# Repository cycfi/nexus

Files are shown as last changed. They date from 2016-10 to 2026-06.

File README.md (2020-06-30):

# Nexus
The Nexus is a small, flexible, and hacker friendly breakout box that connects your multichannel guitar to the outside world using a specialized (LEMO compatible) multi-pin connector for up to 15 channels of audio and 7 channels of analog control voltages for by-wire (remote) control of volume, tone, patch or effects. Audio may come from standard mono-pickups or from the Nu multichannel pickup. Analog control voltages are converted to MIDI control messages.

Refer to this repository to get the Eagle libraries used in our schematic and pcb files: https://github.com/cycfi/eagle_common

Hardware design files licensed under a [Creative Commons Attribution-ShareAlike 4.0 International License](https://creativecommons.org/licenses/by-sa/4.0/).

Software source code distributed under the [MIT License](https://opensource.org/licenses/MIT).

http://www.cycfi.com/

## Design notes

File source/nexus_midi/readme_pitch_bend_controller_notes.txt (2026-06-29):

Pitch Bend Controller
=====================

The pitch bend controller reads the eWhammy pedal's analog sensor and converts
it into 14-bit MIDI pitch bend messages. The whole design exists to solve one
hard problem: keep the output dead-centered at rest (no off-center "latch", no
drift, no crosstalk spikes) WITHOUT flattening real playing -- bends, vibrato,
and slow expressive moves must pass through faithfully.

It is built as a pipeline of small, independently unit-tested processor blocks
(see test/unit_blocks.cpp). The blocks sorted by reusability: the generally
reusable ones (slew_gate, stillness, dc_servo) live in util.hpp; the
pitch-specific ones (inertial_corrector, output_stage, settle_gate,
freeze_watchdog) sit next to this controller in nexus_controls.hpp.

Signal Path (per loop)
----------------------

Each loop the controller runs this chain (pitch_bend_controller::operator()):

  raw_adc            background oversampler -> a 12-bit reading (10-bit ADC
                     + 2 oversampling bits, os_shift = 2; full scale 4095)
    |
  slew_gate          reject faster-than-physical jumps and HOLD the last good
                     reading (not clamp). The arm slews at most ~6 LSB/ms; a
                     programmer-contact glitch shifts the ADC reference ~10x
                     faster, so it is rejected at the source -- the cause of the
                     old off-center latch. Real motion passes untouched.
    |
  dynamic_smoother   adaptive low-pass (re-ported Q / Cytomic). Its cutoff opens
                     with the bandpass energy, so it tracks fast gestures with
                     low lag and smooths hard at rest (G0 = 24, Sense = 128).
                     Replaces the old lp1<8>+lp2<16> cascade (~30 ms release lag).
    |
  settle_gate        STARTUP only: hold the output at center until the input is
                     a genuinely settled rest (in [1600,2560], stable within
                     24 LSB for 300 ms, and at least 5 s past boot). Then seed
                     the C0 servo from it and go live. Suppresses the power-on
                     swing as Vcc ramps; a disconnected pedal stays silently
                     centered and hot-plugs cleanly.
    |
  deflection         (pos - 2048) * 4  ->  a 14-bit signed deflection
    |
  C0 servo (dc_servo)  the live DC center estimate. dev = deflection - C0 is
                     what becomes the output. See "Centering" below.
    |
  inertial_corrector THE sole centering path. Tracks the bend; lands only a
                     HANG (a release that stalls near zero) back to center.
    |
  + center (8192)    offset-binary MIDI form: 8192 = no bend
    |
  out_ma             3-point moving average -- softens a 1-LSB residual toggle
    |
  output_stage       send deadband (+/-16) with a center-snap exception, then
                     the symmetric x1.2 output gain (307/256) applied to ONLY
                     the value handed to MIDI. Emits the 14-bit message.
    |
  freeze_watchdog    last-resort backstop (runs after the send): flush an output
                     that is genuinely stuck off-center back to center.

Centering: the C0 servo + the inertial_corrector
-------------------------------------------------

Centering is split into two decoupled stages so that nothing in the bend path
can feed the center estimate (the old failure mode: a servo that chased the
bend, then stranded the release off-center).

C0 servo (dc_servo<16, 546, 736>) -- the slow baseline. A VERY slow leaky
integrator (tau ~65 s) that tracks ONLY the thermal/mechanical DC drift of the
rest position. It steps toward the raw deflection only when the bar is STILL
(stillness<32,400>: settled within ~2 LSB for 400 ms) AND near neutral
(|dev| <= c0_gate = 546, ~0.8 ST). A real bend (past the gate) FREEZES it, so a
sustained bend is never absorbed as drift. It is hard-clipped to its seed
+/- c0_clip (736, the max physical DC wander), so even a detection slip can
never drag the center onto a real bend.

inertial_corrector -- the return profile. It passes the deflection through
while the bar moves, and lands ONLY a hang: a release that STOPS near zero. The
mechanics:
  * STALL  -- a stop is detected by low-passed SLOPE (slope_k = 3): when the
    smoothed per-loop slope drops below stall_slope = 14, the bar has stopped.
  * ARM    -- landing is armed only after the bar bends past +/-4 ST (bend_th =
    2731): the depth where the hysteresis residual (k*peak) first turns audible.
    A shallower bend never arms -- its tiny residual rides the gate/servo.
  * GATE   -- a hysteresis noise gate (open 68 ~0.10 ST, close 34 ~0.05 ST,
    90 ms dwell) mutes the rest; a vibrato's troughs ride through it (no chop),
    only a real settle re-closes it.
  * LAND   -- a stalled, armed release within hang_band (546) eases to center with
    an EXPONENTIAL decay sized by the descent's PEAK velocity (tau = dist/vpk; both
    the slope vpk and tau are clamped, against a glitch and against a drag). A
    vigorous release lands snappy, a gentle one eases in -- the landing inherits how
    fast you actually moved the bar. The offset is clamped so the land never pulls
    PAST center. The DC is handed off to the slow C0 servo.

This makes the off-center latch structurally impossible while preserving bends
(held, never landed), vibrato (always moving, never stalls), and slow descents
(force-landed -- see the trade below).

Startup
-------

Boot is held MUTED at center until settle_gate confirms a valid settled rest
(see Signal Path). The C0 servo is then seeded from that rest, so the very first
live output is already centered -- no startup swing, no false offset locked in.
A pedal held off-center at boot simply never satisfies the gate and stays muted.

The freeze_watchdog (backstop)
------------------------------

A held bend and a true hang are IDENTICAL instant-to-instant -- both a steady
off-center output -- so only TIME separates them. The watchdog fires only after
the output holds within band = 20, off center by at least off_min = 64, for a
LONG freeze_ms = 10 s (past any real held bend), then flushes: re-seed C0 to the
current deflection, drop the corrector's state, and emit center.

This guards ONE real-world case: an attached programmer's analog loading shifts
the ADC reference (the rest reads ~1 ST off with the bar untouched), past the
C0 gate, so the servo freezes and can't re-center on its own. In normal use (no
programmer attached) the C0 clip bounds the center and the watchdog just sits
idle.

Landing trade: fast snap vs. slow-descent tracking
--------------------------------------------------

The slope-based landing above is the SHIPPED choice (now with the vigor-adaptive
exponential shape). Its one cost is that a deliberately SLOW manual descent
(slower than the sensor noise floor) reads as a stall and is force-landed early
-- the output eases to center while the bar is still gliding down.

A displacement-stall variant tracks those slow descents (lands only after the
bar truly stops) but at a softer ~500 ms landing; a raw-stall "have both"
version got both (snappy AND tracked) at the cost of more machinery. Both were
trialed on hardware and the fast snap won on feel. The slow-descent-tracking
variant is preserved on branch corrector-slow-descents if it is ever wanted.

Output
------

A 14-bit pitch bend message, clamped to 0..16383: 8192 = center (no bend), 0 =
full down, 16383 = full up. The symmetric x1.2 gain (output_stage) fills the
pull side to the rail and clips only the deepest ~17% of the dive, recovering
the full +/-8192 range from a deliberately-linear (un-railed) analog front end.

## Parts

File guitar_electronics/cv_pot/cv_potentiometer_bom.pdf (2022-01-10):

CV POTENTIOMETER
Item | Description | Part Number | Packaging | Manufacturer | Location | Qty.
1 | 1x3 Male Header, SMD | M20-8900305 | 2.54mm | Harwin | H1 | 1
2 | 0.1uF | CL05A104KA5NNNC | C0402 | Samsung Electro-Mechanics | C1 | 1
3 | 1uF | CC0603KRX5R8BB105 | C0603 | YAGEO | C2, C3 | 2
4 | 2k Ohms | RK73H1ETTP2001F | R0402 | KOA Speer Elec | R1 | 1
5 | 10k Ohms Pot | PDB181-GTR01-103B0 | - | Bourns | POT1 | 1
6 | 5V Regulator | CJ75L05 | SOT 89 | Changjiang Electronics Tech (CJ) | U1 | 1
7 | Single Opamp | TLV6001IDBVR | SOT 23 5 | Texas Instruments | U2 | 1

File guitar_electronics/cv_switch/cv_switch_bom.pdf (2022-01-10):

5-WAY CV SWITCH
Item | Description | Part Number | Packaging | Manufacturer | Location | Qty.
1 | 1x3 Male Header | 22-28-4035 | 2.54mm | Molex | H1 | 1
2 | 1uF | CC0603KRX5R8BB105 | C0603 | YAGEO | C1,C2 | 2
3 | 10uF | GRM188R61E106KA73D | C0603 | Murata | C3 | 1
3 | 1.5k Ohms | ERA2AEB152X | R0402 | PANASONIC | R1, R4 | 2
4 | 3k Ohms | ERA2AEB302X | R0402 | PANASONIC | R2, R3 | 2
5 | 5V Regulator | CJ75L05 | SOT 89 | Changjiang Electronics Tech (CJ) | U1 | 1
6 | 5 Way Switch | LSW56 | - | - | - | 1

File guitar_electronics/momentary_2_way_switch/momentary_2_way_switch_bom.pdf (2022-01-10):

2-WAY SWITCH
Item | Description | Part Number | Packaging | Manufacturer | Location | Qty.
1 | 1x3 Male Header, SMD | M20-8900305 | 2.54mm | Molex | H1 | 1
3 | 10uF | GRM188R61E106KA73D | C0603 | Murata | C1, C2 | 2
3 | 1k Ohms | RT0402DRE071KL | R0402 | YAGEO | R1, R2 | 2
5 | Schotkky Diode | CUS551V30,H3F | SOD323 | Toshiba | D1, D2 | 2
6 | Momentary Toggle Switch | 100SP4T1B1M1QEH | - | - | S1 | 1

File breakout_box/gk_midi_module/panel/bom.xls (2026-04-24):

Comment | Designator | Footprint | JLCPCB Part #
5VVoltageRegulator | U4 | SOT-89 | C2079
470nF | C13 | C0603 | C1623
2.2uF | C33 | C0805 | C377773
16MhzCrystalOscillator | X1 | HC-49/US | C16212
10kΩ | R19,R27,R28,R29,R35,R36,R37 | R0402 | C25744
3.3VVoltageRegulator | U5 | SOT23-5 | C37970
SwitchingDiode | D1,D2 | SOT-323-3 | C8662
100kΩ | R1,R2,R3,R4,R5,R6 | R0402 | C25741
100nF | C3,C4,C5,C6,C7,C8,C10,C12,C17,C18,C19,C20,C21,C23,C24,C25,C26,C28,C29,C34 | C0603 | C14663
DualOpamp | U1,U3 | VSSOP-8 | C2059027
12pF | C36,C37 | C0603 | C38523
100uF | C1,C2 | 6.3x5.7 | C249967
220Ω | R30,R31 | R0603 | C22962
4.7uF | C15,C16 | C0603 | C19666
16-bitMicrocontroller | U6 | QFN-32 | C27832
QuadOpamp | U2 | TSSOP-14 | C882743
10uF,25V | C9,C11,C22,C32 | C0805 | C15850
1uF,25V | C27,C30 | C0402 | C52923
1kΩ | R32,R33,R34 | R0402 | C11702
47kΩ | R41 | R0402 | C25792
5.1kΩ | R7,R8,R9,R10,R11,R12,R13,R14,R15,R16,R17,R18,R24,R25,R26,R38,R39,R40 | R0402 | C25905
FerriteBead | FB1,FB2 | R0603 | C113029
100Ω | R22,R23 | R0603 | C22775
18kΩ | R20 | R0402 | C25762
GeneralPurposeNPNTransistor | T1,T2 | SOT23-3 | C82460
1nF | C35 | C0402 | C1523
470kΩ | R21 | R0402 | C25790
10nF | C14 | C0402 | C15195
33uF | C31 | C0805 | C432920

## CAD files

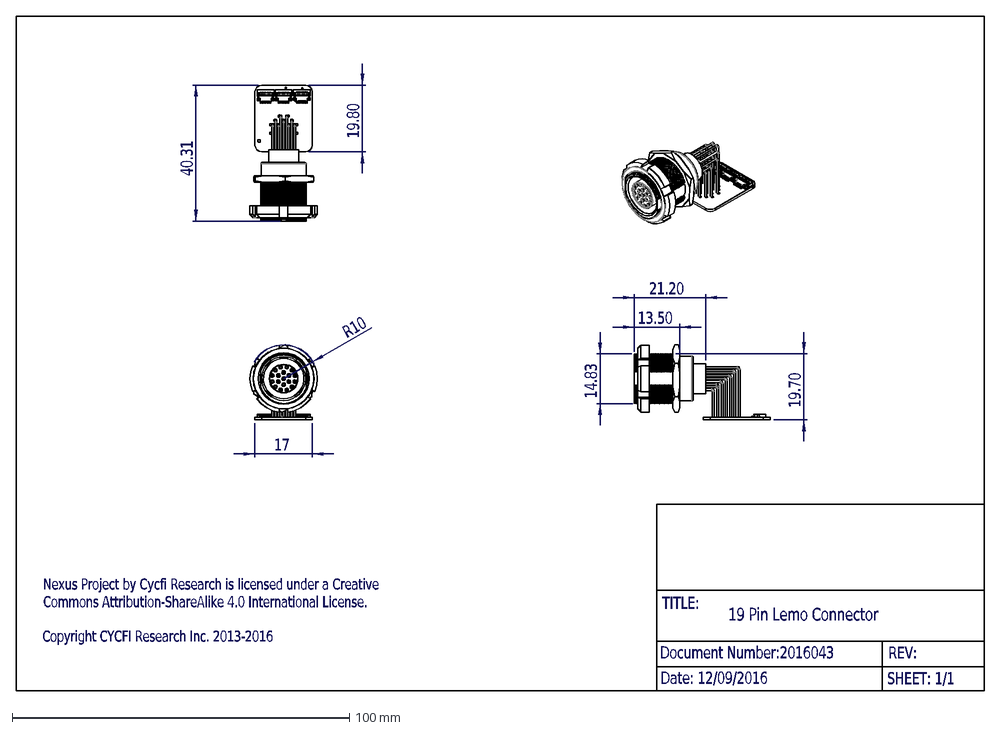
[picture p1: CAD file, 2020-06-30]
cad_drawings/19p_connector.dxf
Nexus Project by Cycfi Research is licensed under a Creative
Commons Attribution-ShareAlike 4.0 International License.
Copyright CYCFI Research Inc. 2013-2016
19 Pin Lemo Connector
TITLE:
Document Number:2016043
Date: 12/09/2016
REV:
SHEET: 1/1
R10
17
40.31
19.80
21.20
13.50
14.83
19.70

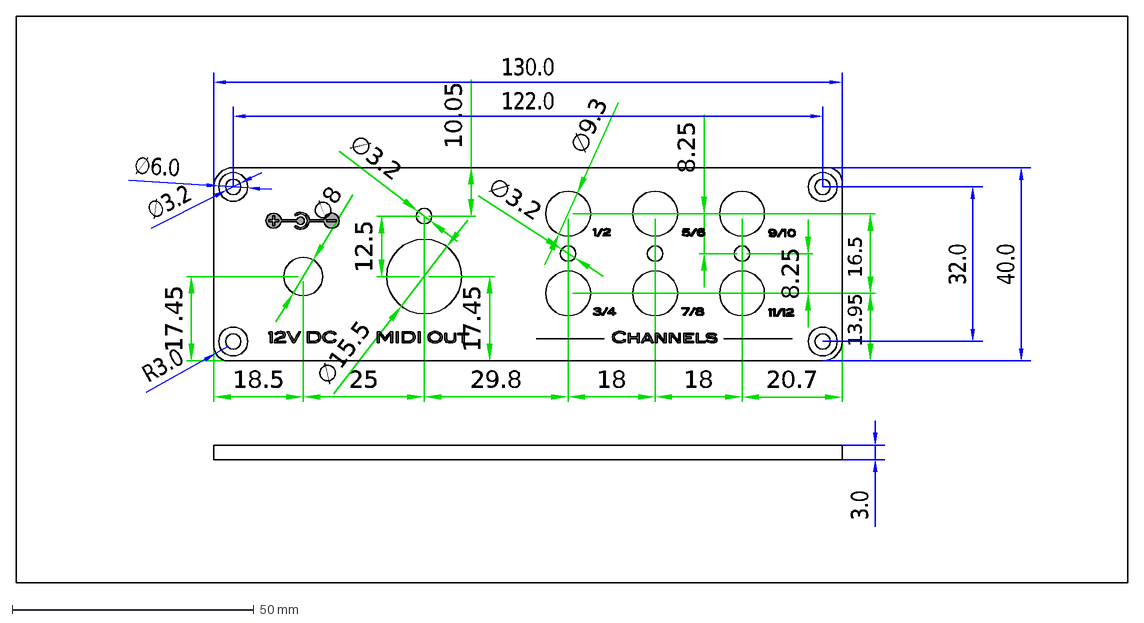
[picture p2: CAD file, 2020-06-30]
cad_drawings/nexus_back_panel.dxf
18.5
25
16.5
20.7
18
17.45
10.05
29.8
∅8
∅15.5
∅3.2
∅9.3
13.95
8.25
40.0
130.0
3.0
32.0
122.0
∅6.0
R3.0
12.5

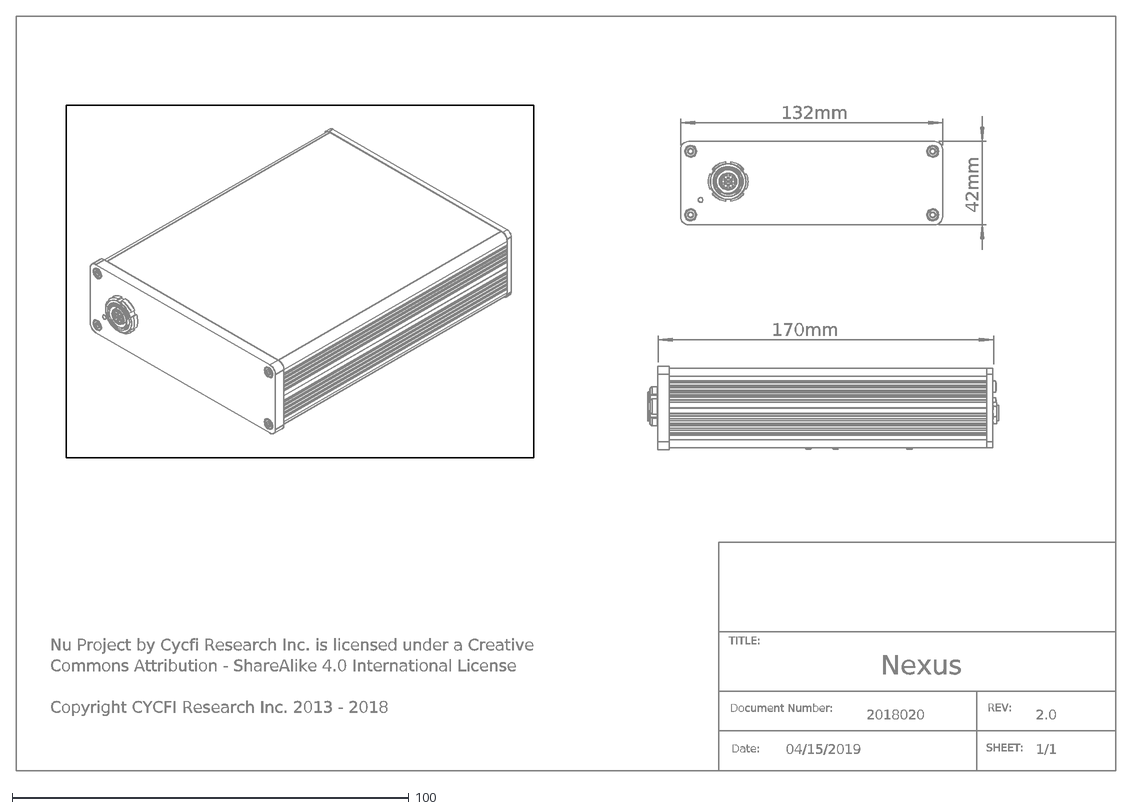
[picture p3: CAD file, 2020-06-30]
cad_drawings/nexus.dxf
42mm
132mm
170mm
Nexus
2018020
04/15/2019
1/1
2.0
TITLE:
Document Number:
Date:
REV:
SHEET:
Nu Project by Cycfi Research Inc. is licensed under a Creative
Commons Attribution - ShareAlike 4.0 International License
Copyright CYCFI Research Inc. 2013 - 2018

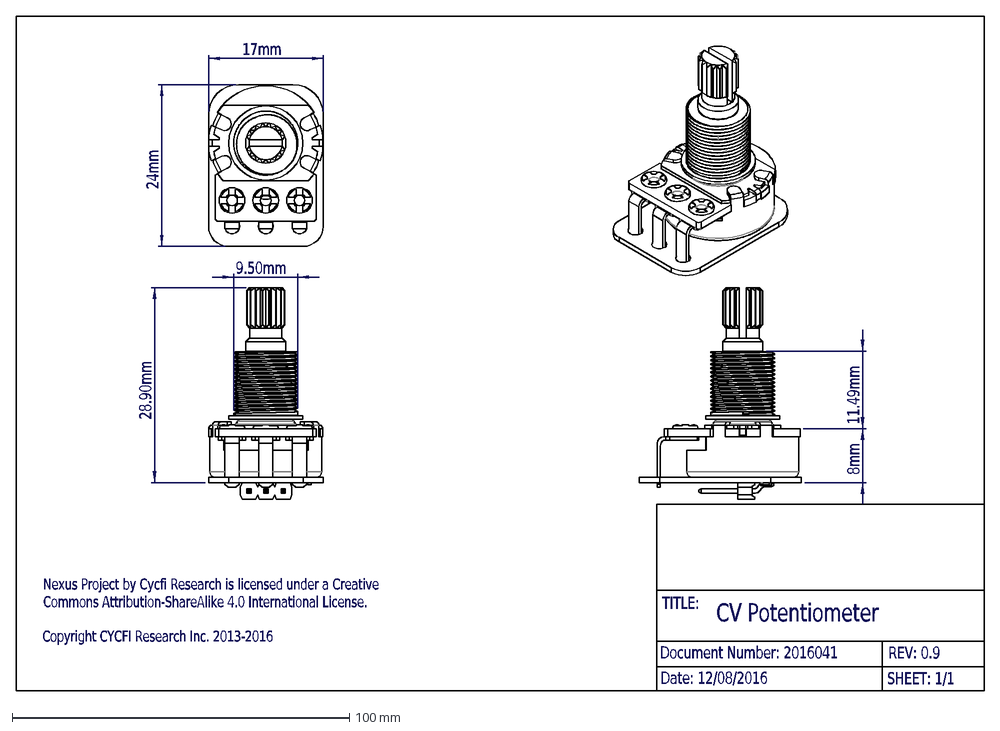
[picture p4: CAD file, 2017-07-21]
cad_drawings/cv_pot.dxf
Nexus Project by Cycfi Research is licensed under a Creative
Commons Attribution-ShareAlike 4.0 International License.
Copyright CYCFI Research Inc. 2013-2016
CV Potentiometer
TITLE:
Document Number: 2016041
Date: 12/08/2016
REV: 0.9
SHEET: 1/1
28.90mm
9.50mm
8mm
11.49mm
17mm
24mm

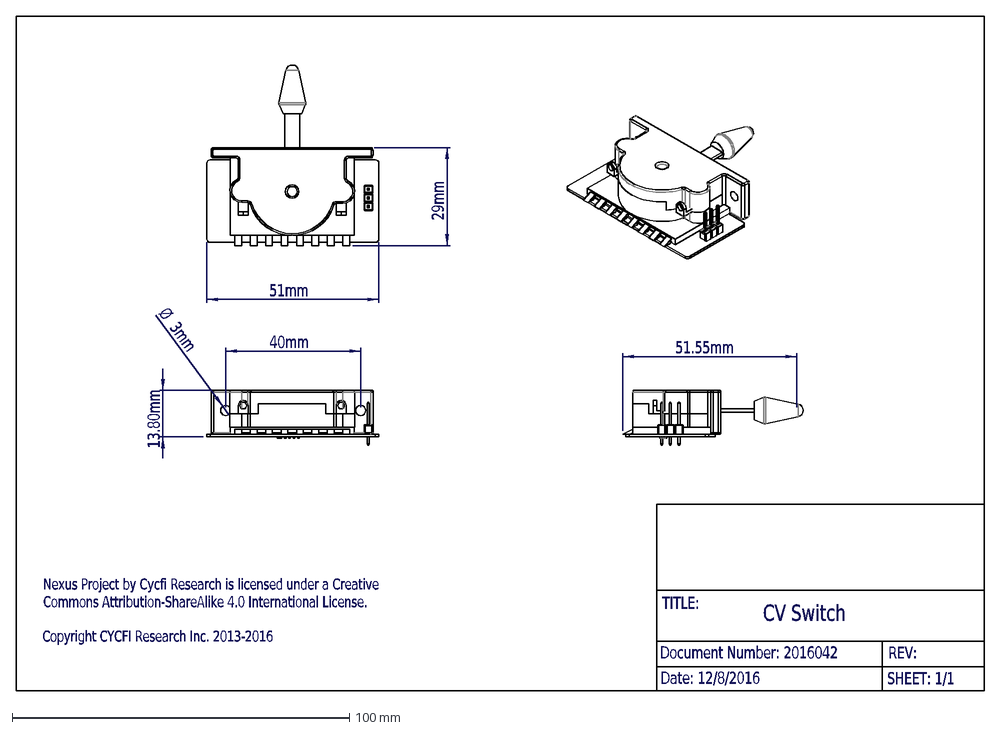
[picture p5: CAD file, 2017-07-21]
cad_drawings/cv_switch.dxf
Nexus Project by Cycfi Research is licensed under a Creative
Commons Attribution-ShareAlike 4.0 International License.
Copyright CYCFI Research Inc. 2013-2016
CV Switch
TITLE:
Document Number: 2016042
Date: 12/8/2016
REV:
SHEET: 1/1
13.80mm
40mm
Ø
3mm
29mm
51mm
51.55mm

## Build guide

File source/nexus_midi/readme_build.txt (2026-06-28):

Building nexus_midi (CMake + Energia MSP430 toolchain)
======================================================

This builds the MSP430G2553 firmware from the command line with CMake. It
reuses the compiler, core, variant, and MspFlash library that Energia installs,
so the Energia IDE does not need to be open — but Energia (with its MSP430
platform) does need to be installed.

Requirements
------------
- CMake 3.14 or later.
- Energia, installed via its board manager, including:
    - the MSP430 platform  (energia/hardware/msp430/1.0.7)
    - the bundled toolchain (msp430-gcc 4.6.6)
  The default location is:
      ~/Library/Energia15/packages/energia
  If yours differs, pass -DENERGIA_ROOT=<path to .../packages/energia>.
- mspdebug, for flashing:  brew install mspdebug
- A host C++ compiler (clang/gcc) for the off-device test harness (below).

Build (device firmware)
-----------------------
    cd source/nexus_midi
    cmake -B build -DCMAKE_TOOLCHAIN_FILE=cmake/msp430_toolchain.cmake
    cmake --build build

Outputs land in build/:
    nexus_midi.elf    the linked firmware
    nexus_midi.hex    Intel HEX, for flashing
A flash/RAM size report is printed at the end of the build. The current
production image is ~9234 B flash (text 9230 + data 4) and 330 B RAM (bss 326 +
data 4) on the 16 KB / 512 B G2553.

Two build-time options (both default OFF -> the production image):
  -DNEXUS_DIAG=ON   SysEx telemetry for the pitch bend (free-running state +
                    spike snapshots). The BENCH build: flash this to record and
                    diagnose. Adds ~600 B of .text. Keep it in its own dir:
        cmake -B build_diag -DCMAKE_TOOLCHAIN_FILE=cmake/msp430_toolchain.cmake -DNEXUS_DIAG=ON
        cmake --build build_diag
  -DNEXUS_SIM=ON    Route raw_adc() to a synthetic ADC generator on-device (a
                    hardware-in-the-loop self-stimulus). Rarely needed on device;
                    the host harness below is the usual way to run the sim.

Tests (host-side, off device)
-----------------------------
A standalone CMake project under test/ compiles the firmware blocks with the
HOST compiler (do NOT pass the MSP430 toolchain file). Two executables:

    cmake -S test -B test/build
    cmake --build test/build
    ./test/build/unit_blocks     # per-block contracts, each block in isolation
    ./test/build/host_sim        # whole-loop replay of a synthetic gesture suite
    ctest --test-dir test/build  # or run both via CTest

- unit_blocks (NEXUS_HOST): exercises each processor block (slew_gate, stillness,
  dc_servo, output_stage, settle_gate, adc::decimate, ...) in isolation, so a
  failure localizes to one block.
- host_sim (NEXUS_HOST + NEXUS_SIM): runs the full pitch-bend pipeline against a
  deterministic synthetic stimulus and asserts the decoded MIDI stream. It also
  takes --feed <csv> to REPLAY a real captured ADC session (see
  test/replay_captures.py), which is the primary center-stability regression.

Both are the integration + unit gate for firmware changes; run them before
flashing. (After switching git branches use --clean-first for the host build —
CMake can miss a header-only dependency and leave a stale binary.)

Flashing
--------
A classic MSP430G2 LaunchPad's onboard FET uses the mspdebug rf2500 driver. The
convenience target flashes the production image:

    cmake --build build --target upload

To flash any specific image directly (e.g. the diag build) with the same driver:

    mspdebug rf2500 --force-reset "prog build_diag/nexus_midi.hex"

For a newer MSP-EXP430G2ET board (eZ-FET), flash with tilib instead:

    mspdebug tilib --force-reset "prog build/nexus_midi.hex"

If the FET wedges (error code 4 / reply-type mismatch), USB power-cycle the
LaunchPad and retry. The eWhammy target has its own power; unplugging the
programmer (SBW) does not kill it but shifts the ADC reference.

How it works
------------
- cmake/msp430_toolchain.cmake points CMake at the Energia-bundled
  msp430-gcc / msp430-g++ (tools/msp430-gcc/4.6.6) and sets -mmcu=msp430g2553.
- CMakeLists.txt mirrors Energia's platform.txt recipe (same flags and
  defines), compiles the Energia core + MspFlash into a static library, and
  links the firmware the way Energia does (with msp430-gcc, -fno-exceptions
  -fno-rtti -Wl,--gc-sections,-u,main).
- The sketch stays a .ino so the Energia IDE still works. The build generates
  build/nexus_midi.cpp from it (via cmake/gen_sketch.cmake, prepending
  <Energia.h>) and compiles that.

Equivalence to the Energia IDE build
------------------------------------
The CMake build mirrors Energia's platform.txt recipe exactly (flags, defines,
core sources, link), and was verified byte-for-byte against the IDE's own build
of the same source — only the absolute link addresses differ. That check was on
an earlier, smaller image (7548 B); the recipe is unchanged, so the equivalence
holds. See the size report at the end of the build for the current numbers.

Targeting another part
----------------------
Defaults to MSP430G2553 / MSP-EXP430G2553LP. For another value-line part pass
-DMSP430_MCU=<part> and use the matching variant headers.

Notes
-----
- The device toolchain is msp430-gcc 4.6.6, which is C++11-incomplete: no NSDMI
  (use explicit constructors), narrowing brace-init is only a warning, etc. The
  lenient host build can hide errors the device build rejects, so always confirm
  build_diag (the device build) compiles, not just the host harness.
- A source-level debug build (-g -Og, for msp430-gdb) is not wired up yet; the
  default build matches Energia's release flags (-Os). You can still debug the
  release image at runtime via mspdebug (setbreak / regs / md).

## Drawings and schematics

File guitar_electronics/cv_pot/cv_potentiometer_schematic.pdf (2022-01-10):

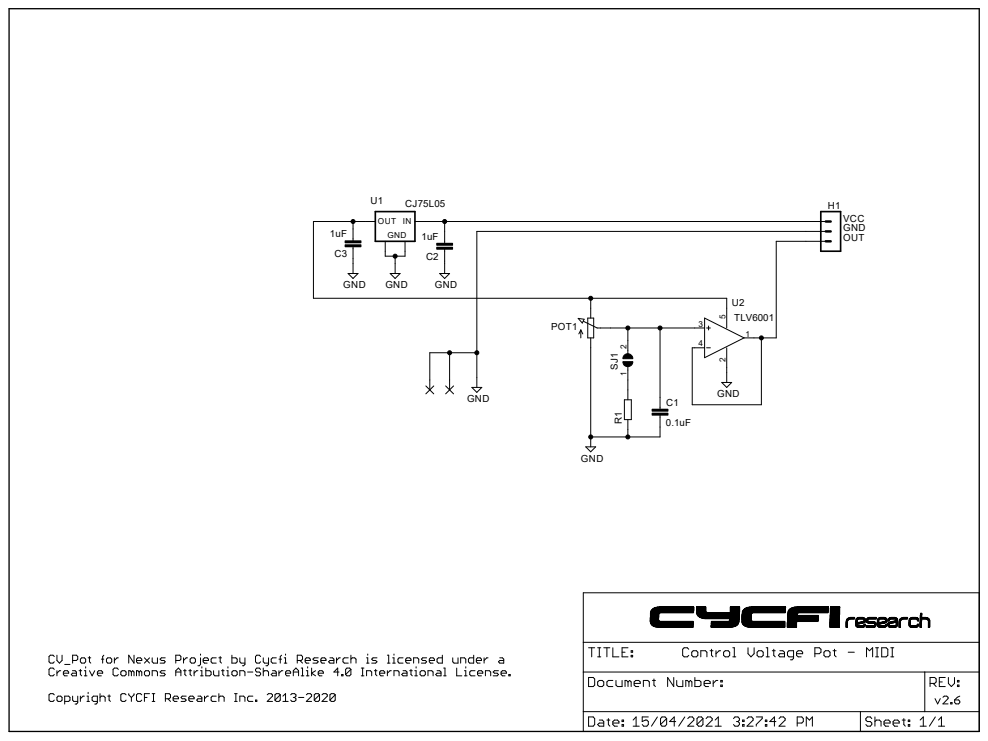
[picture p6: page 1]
GND; TLV6001; VCC GND OUT; POT1; OUT IN

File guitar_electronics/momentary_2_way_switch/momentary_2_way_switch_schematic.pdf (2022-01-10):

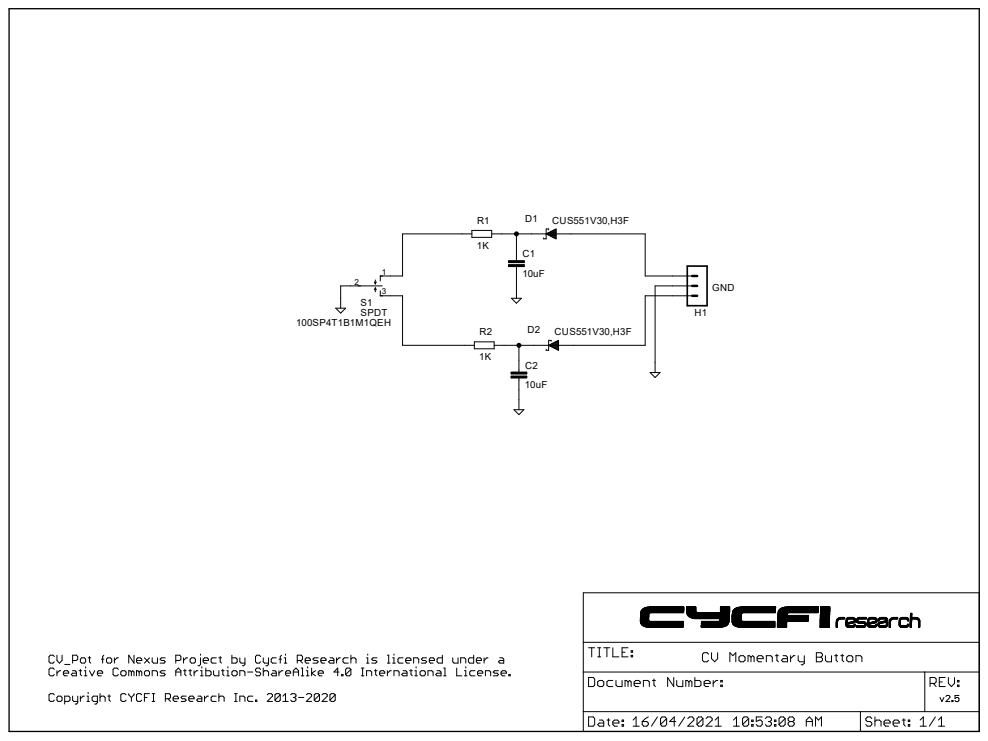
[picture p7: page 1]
CUS551V30,H3F; SPDT; GND; 100SP4T1B1M1QEH

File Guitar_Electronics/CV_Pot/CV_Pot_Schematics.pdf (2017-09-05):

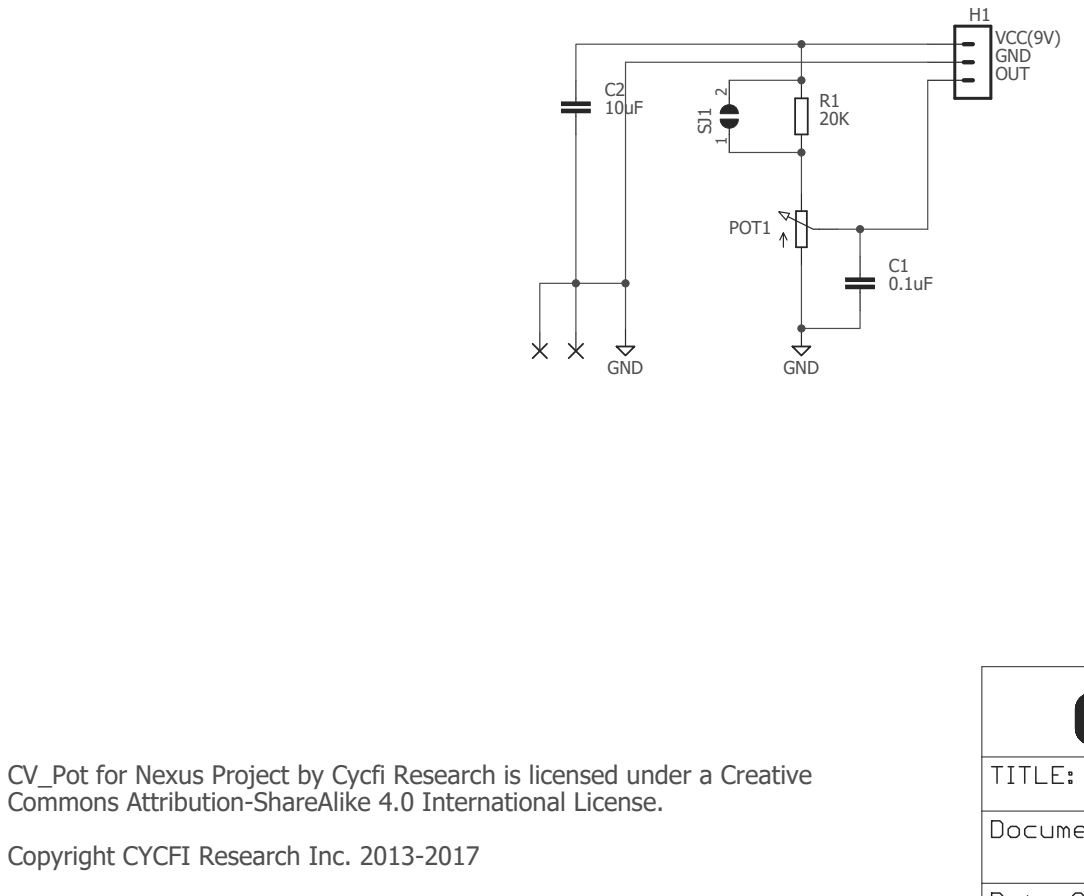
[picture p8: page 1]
GND; VCC(9V) GND OUT; POT1

CV_Pot for Nexus Project by Cycfi Research is licensed under a Creative
Commons Attribution-ShareAlike 4.0 International License.
Copyright CYCFI Research Inc. 2013-2017

Control Voltage Pot - MIDI

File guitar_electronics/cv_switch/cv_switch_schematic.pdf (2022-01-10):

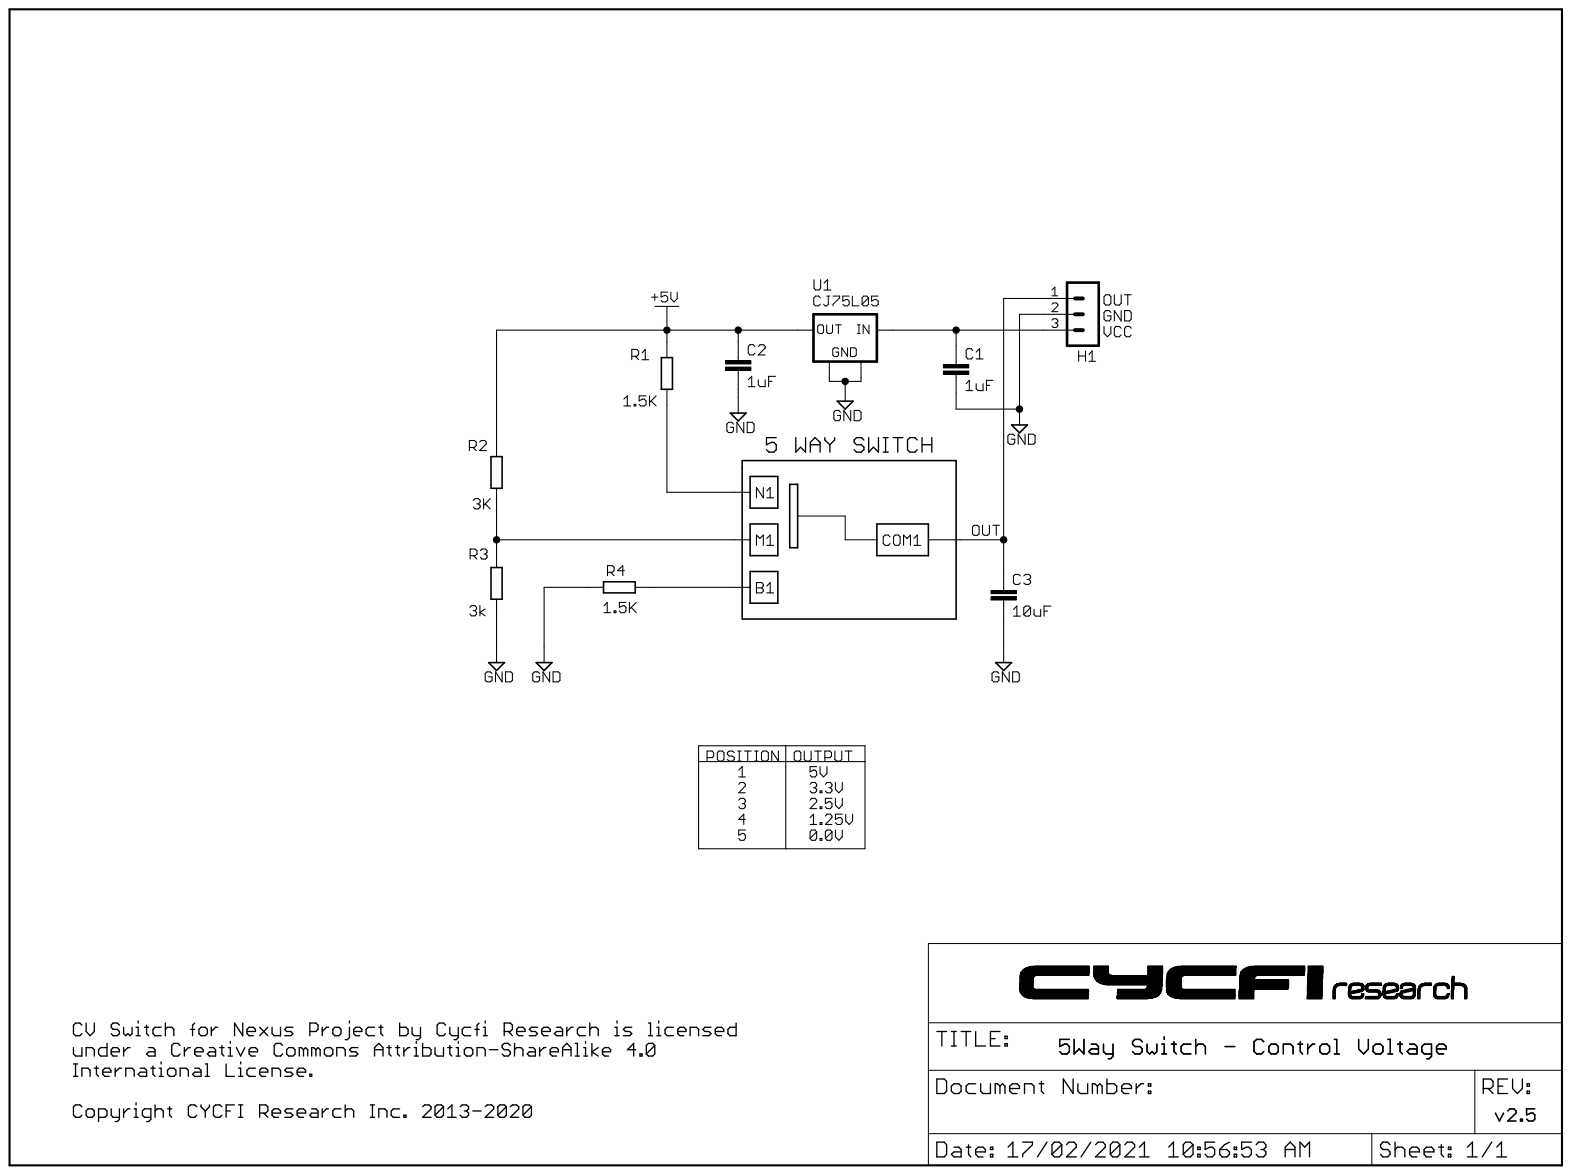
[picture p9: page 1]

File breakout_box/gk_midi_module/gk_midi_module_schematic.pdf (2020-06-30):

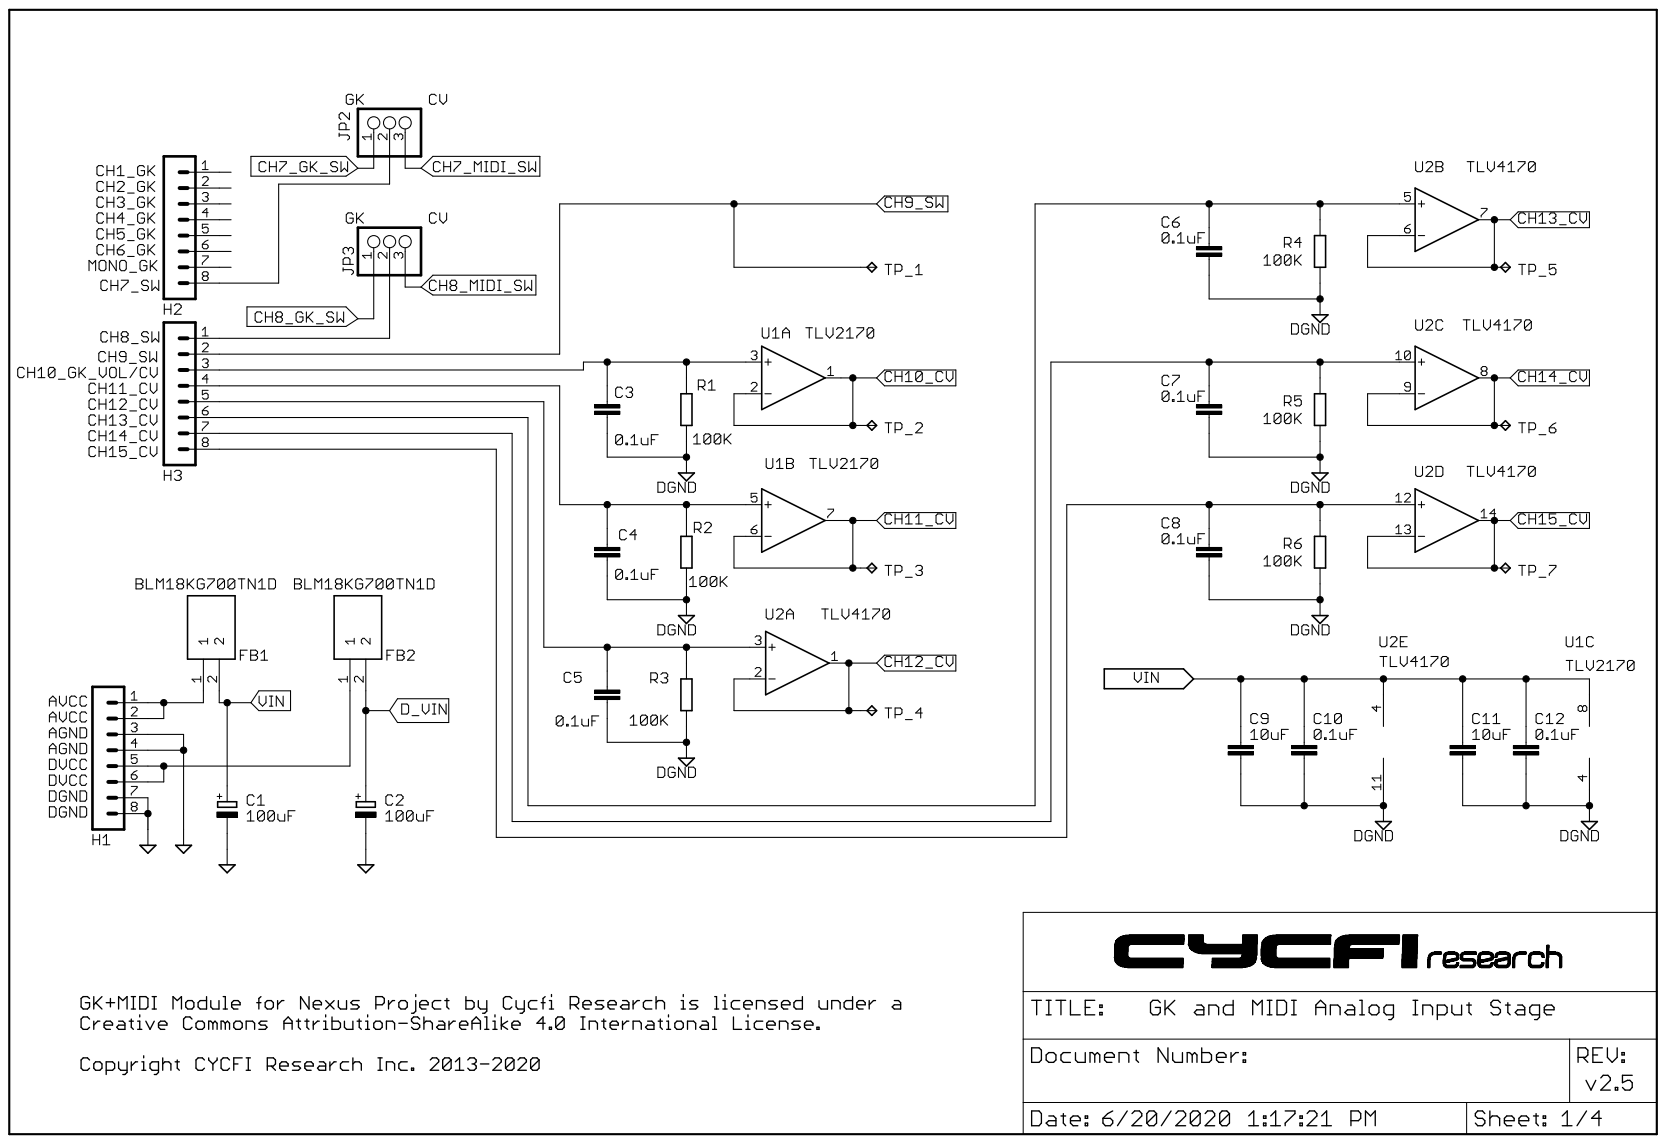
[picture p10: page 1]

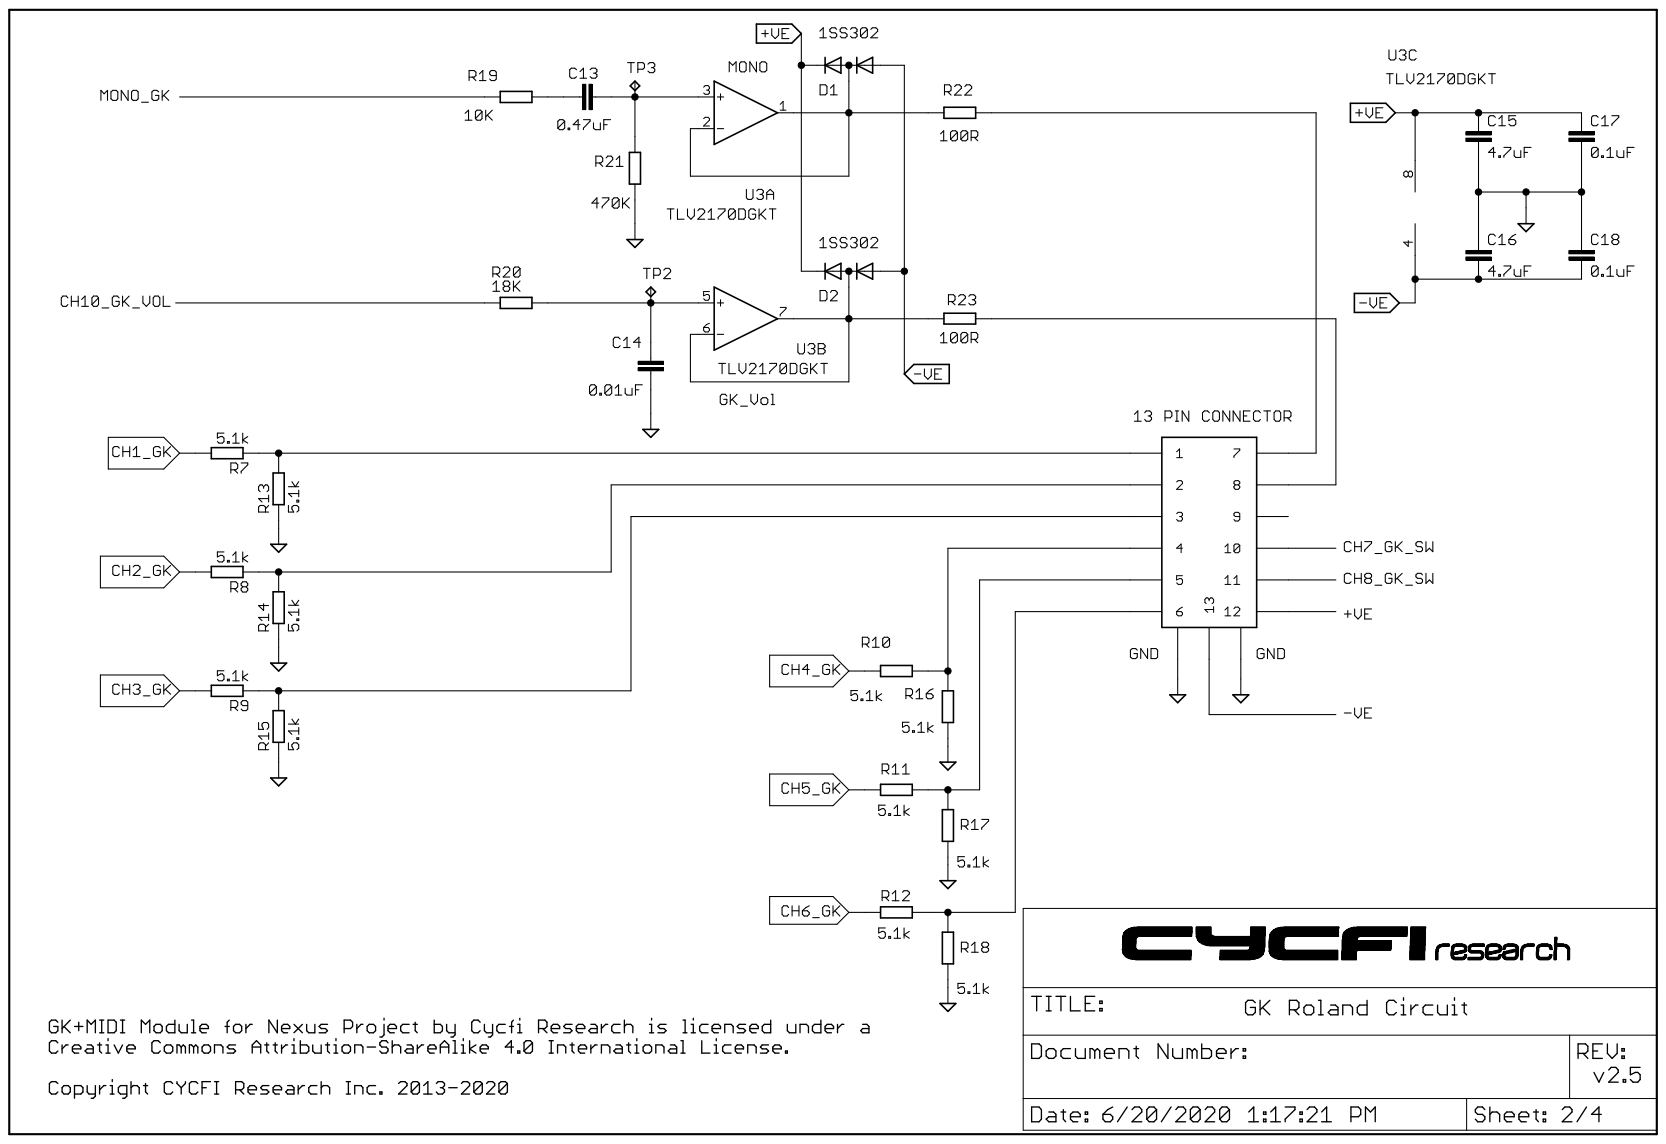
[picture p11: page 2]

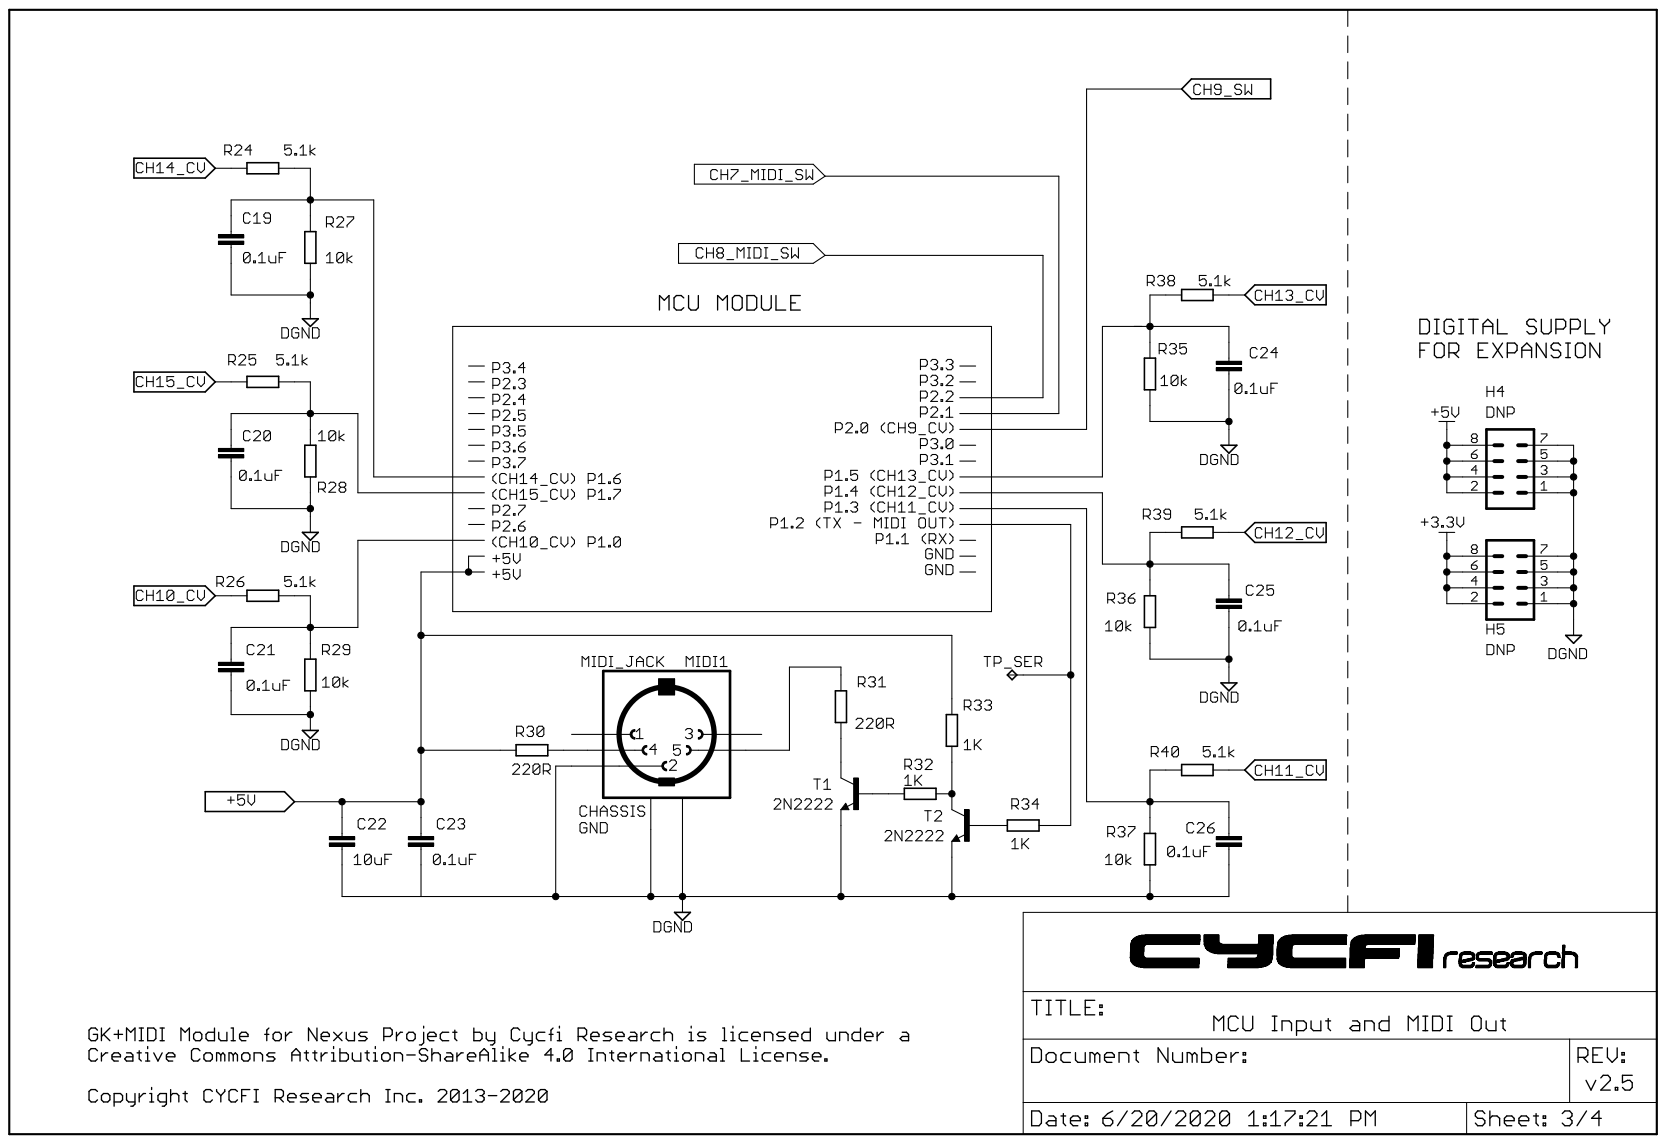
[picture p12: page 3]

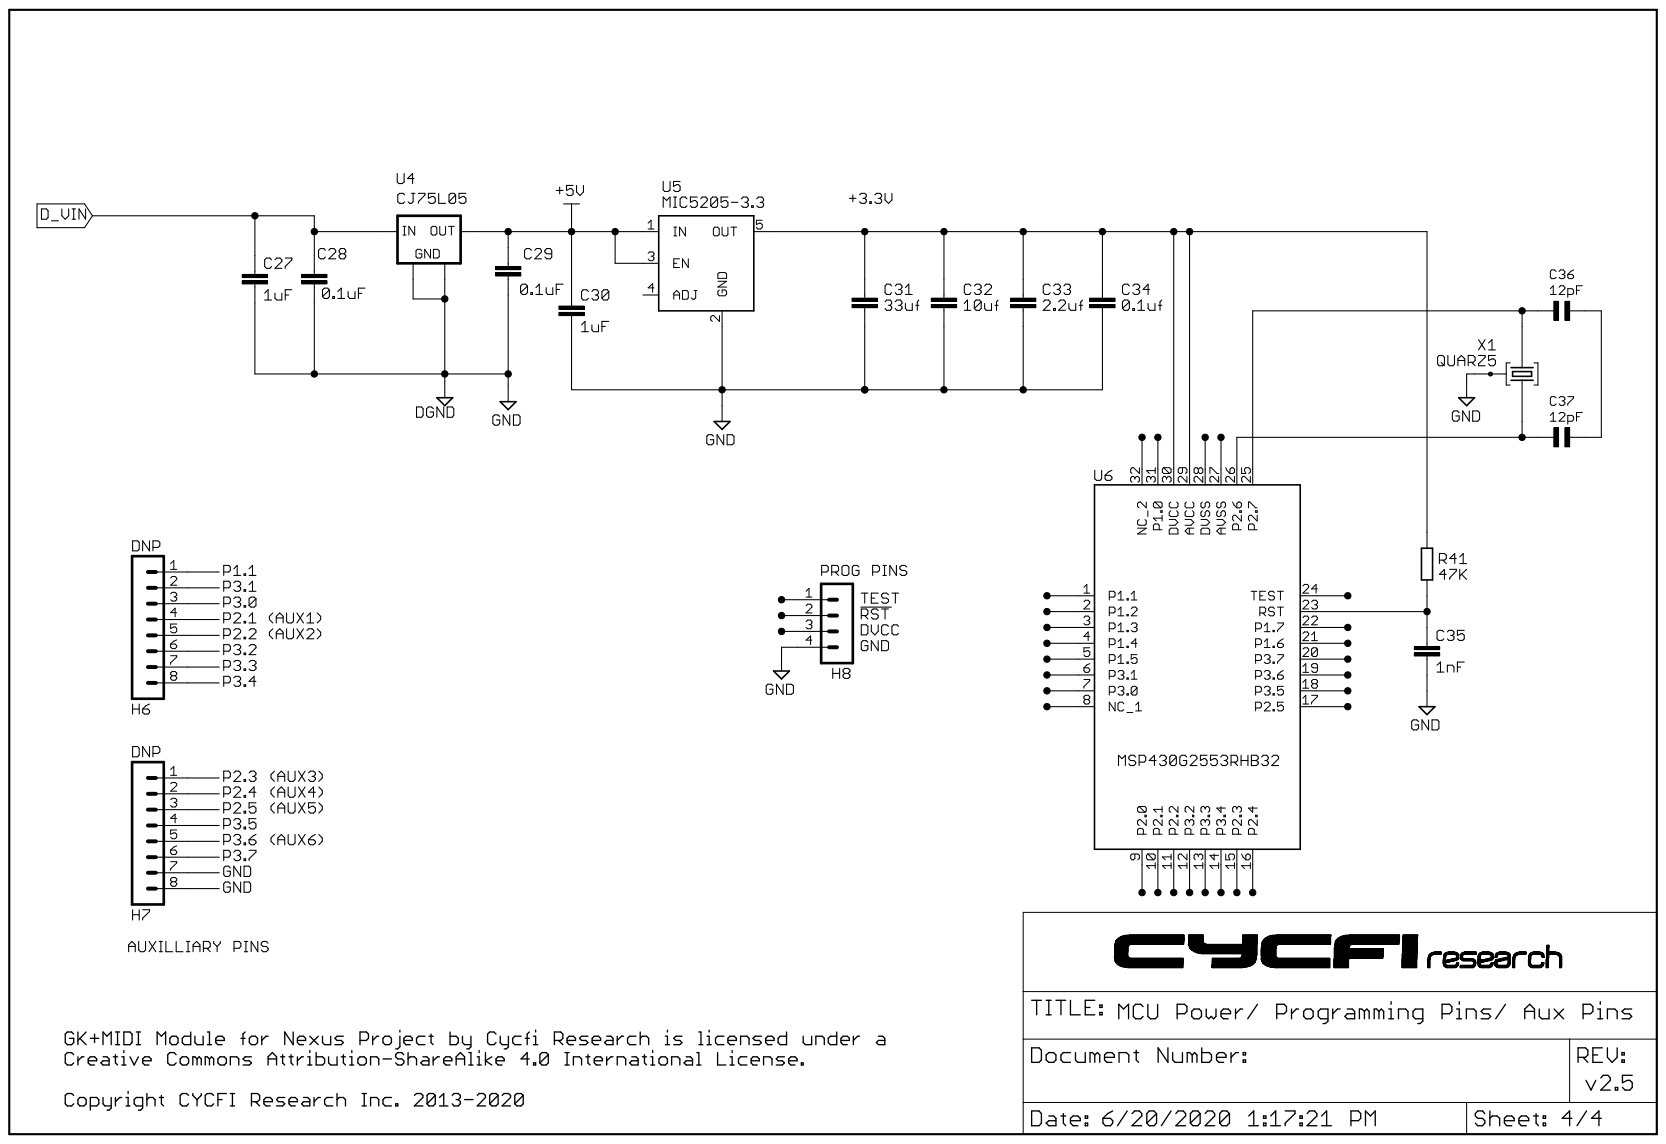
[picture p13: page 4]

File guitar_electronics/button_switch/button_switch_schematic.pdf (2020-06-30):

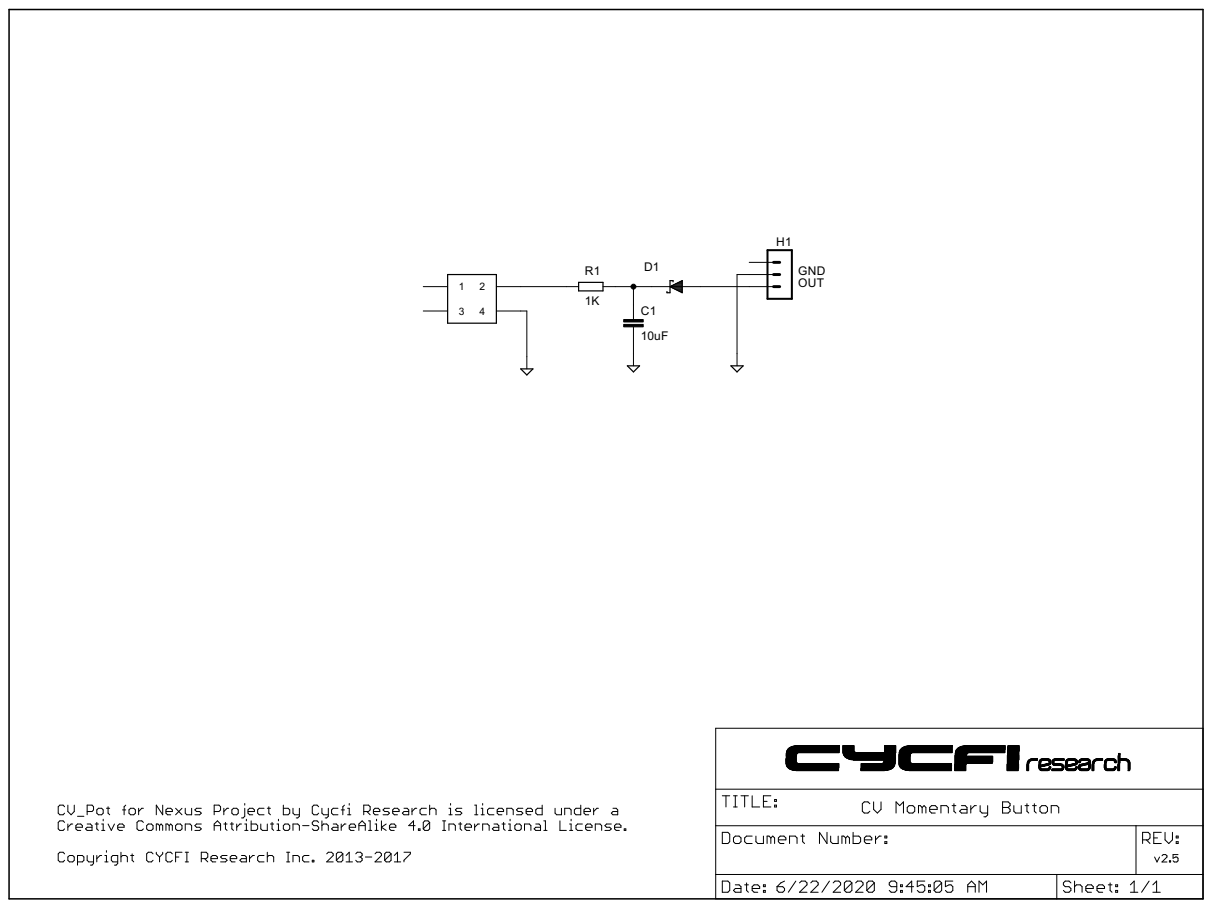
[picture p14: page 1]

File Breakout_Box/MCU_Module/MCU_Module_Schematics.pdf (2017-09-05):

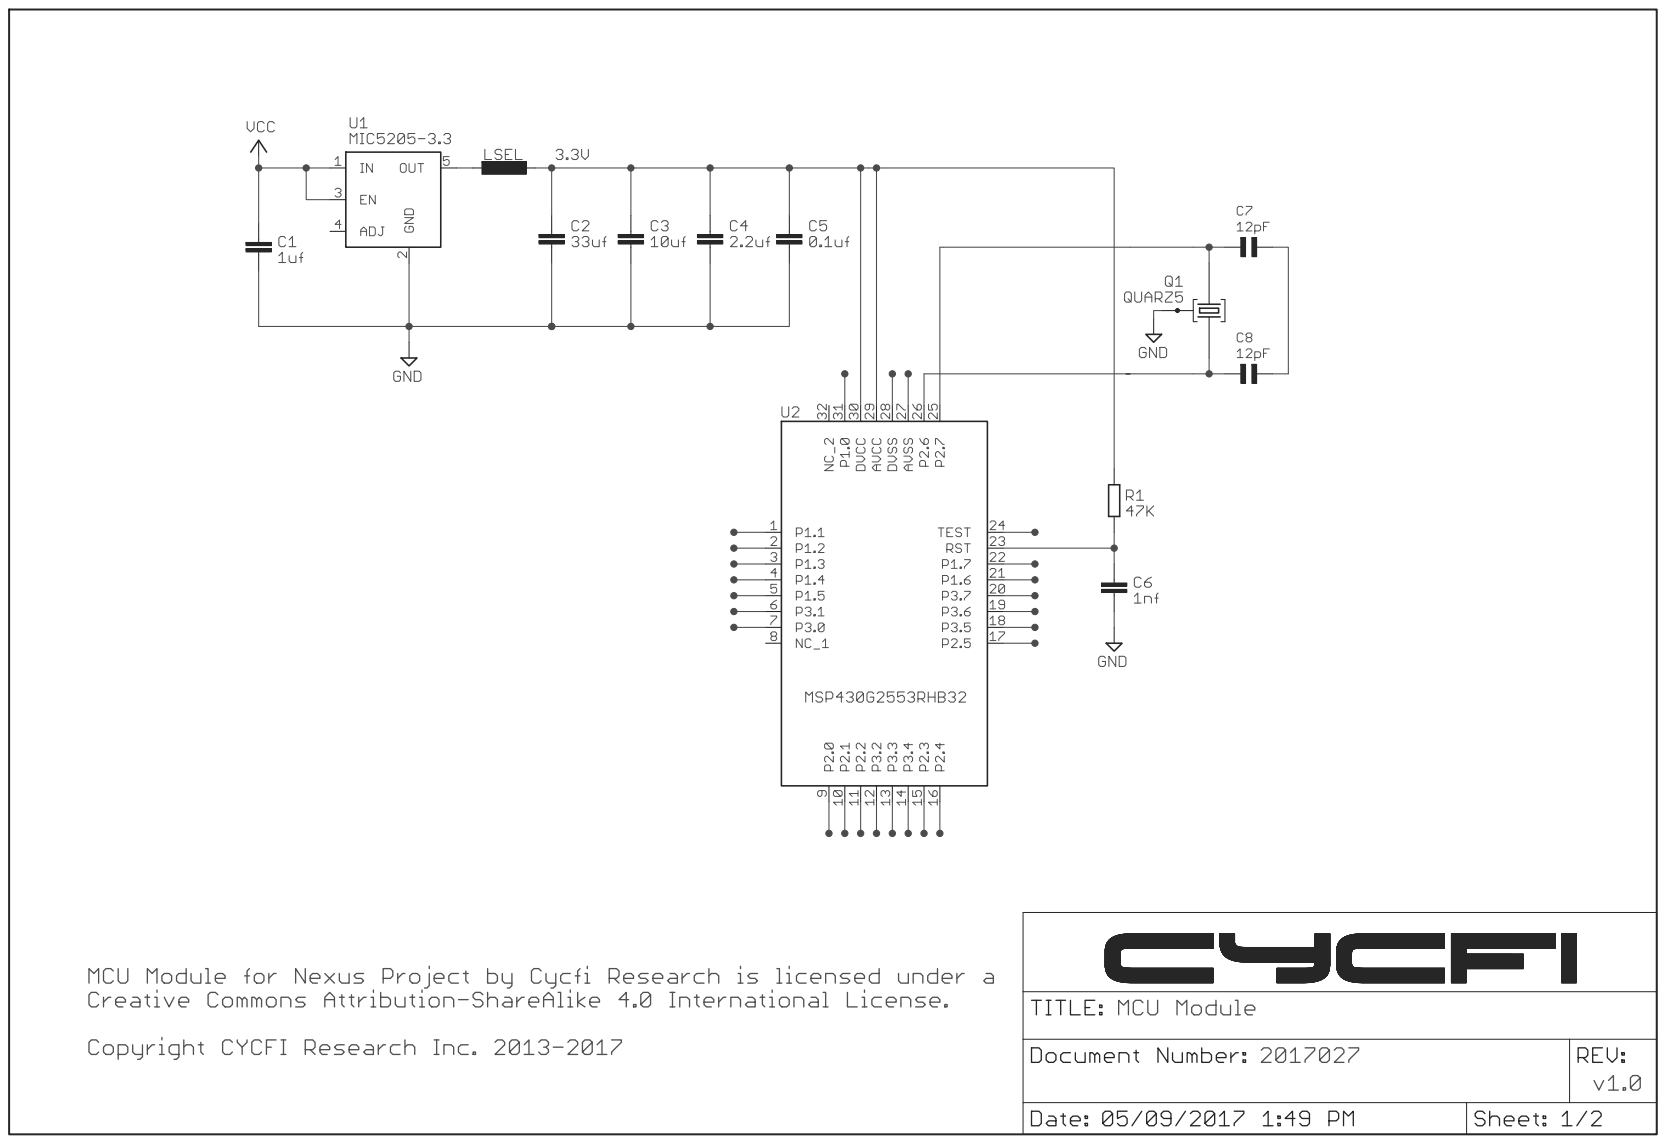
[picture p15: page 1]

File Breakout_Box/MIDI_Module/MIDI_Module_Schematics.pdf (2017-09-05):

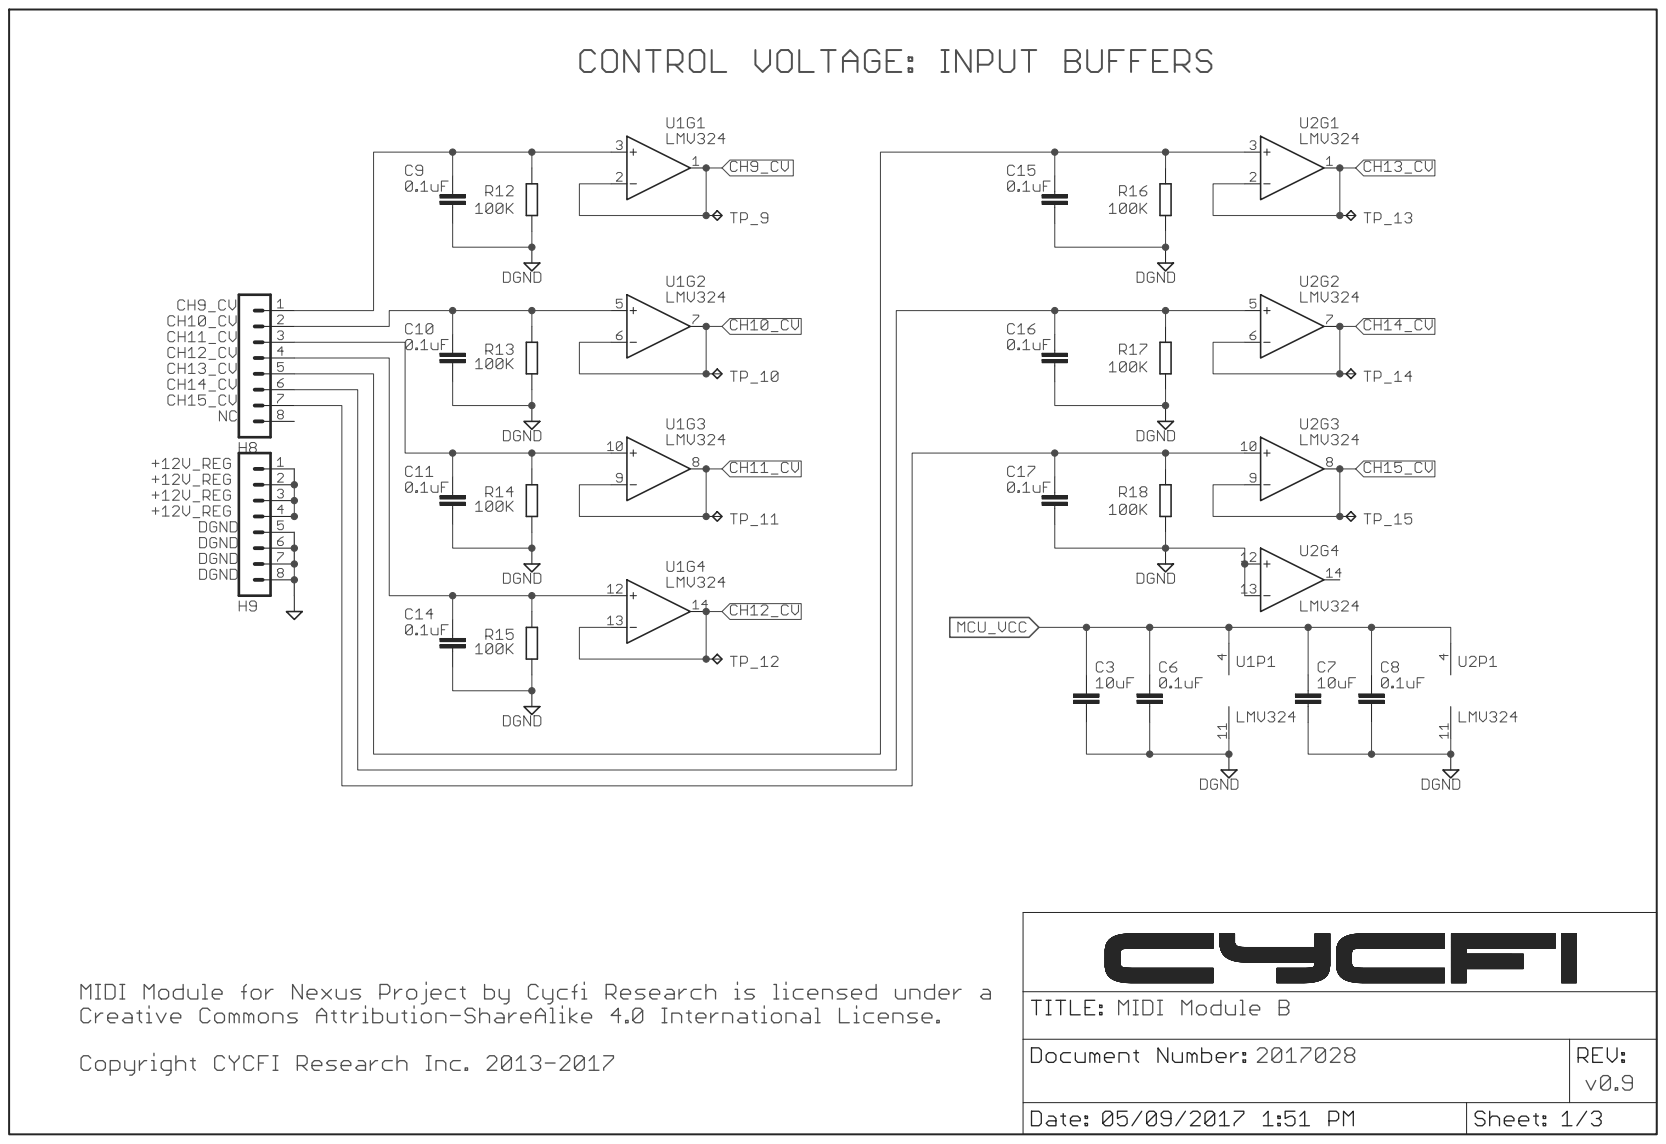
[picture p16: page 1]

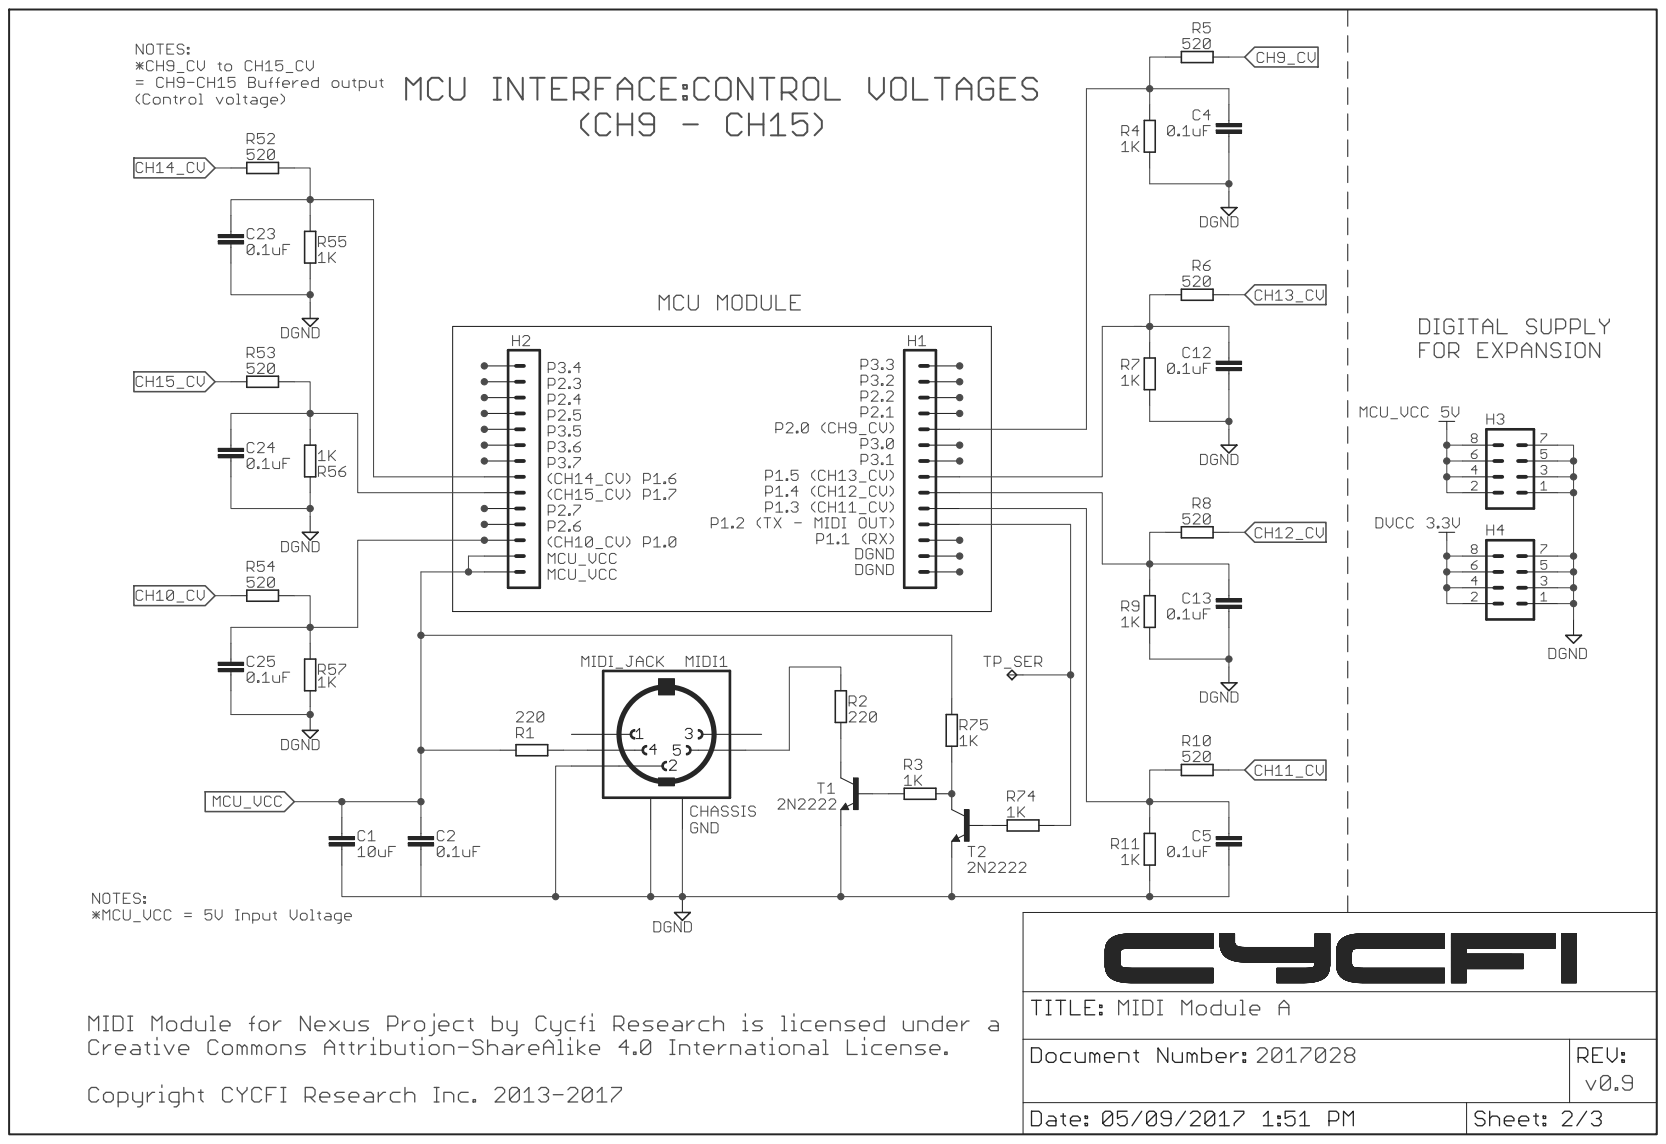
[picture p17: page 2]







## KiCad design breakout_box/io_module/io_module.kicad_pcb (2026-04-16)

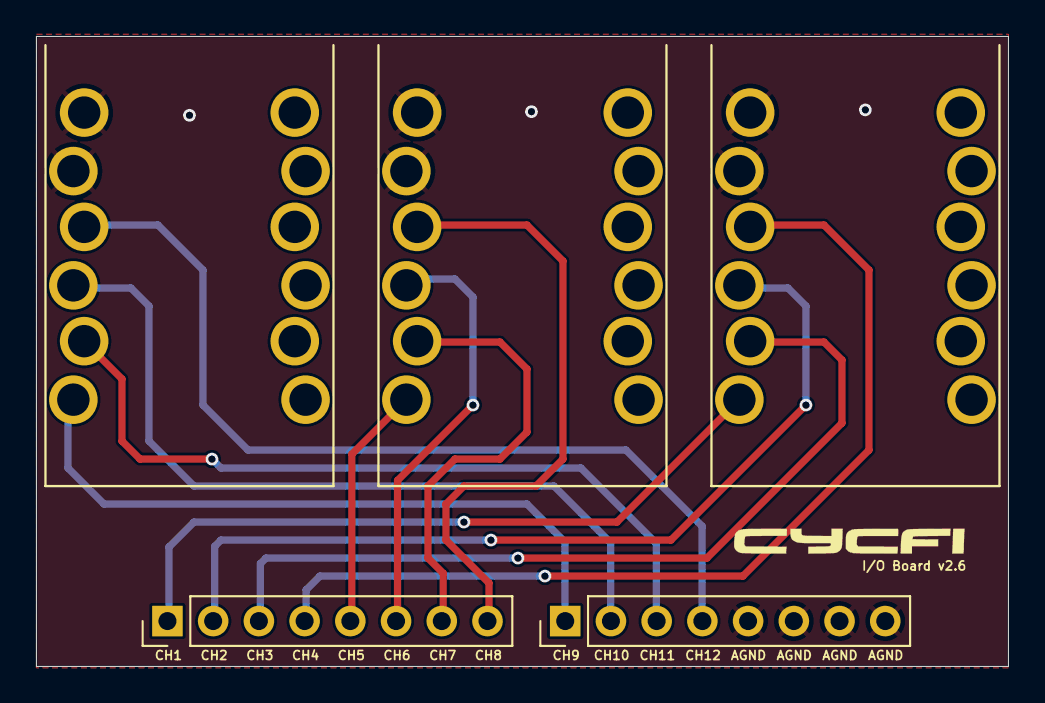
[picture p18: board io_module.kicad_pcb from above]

Board: 2 copper layers, 54.0 x 35.0 mm, 5 parts (0 on the bottom side), 13 nets.

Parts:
H1, H2: MA08-1; PinHeader_1x08_P2.54mm_Vertical
J1, J2, J3: ZHEJINAG_CK_STSJACKS; ZHEJINAG_CK_6.35

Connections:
AGND: H2.5, H2.6, H2.7, H2.8, J1.2S (S), J1.S, J2.2S (S), J2.S, J3.2S (S), J3.S
CH1: H1.1, J1.2T (T)
CH2: H1.2, J1.2R (R)
CH3: H1.3, J1.T
CH4: H1.4, J1.R
CH5: H1.5, J2.2T (T)
CH6: H1.6, J2.2R (R)
CH7: H1.7, J2.T
CH8: H1.8, J2.R
CH9: H2.1, J3.2T (T)
CH10: H2.2, J3.2R (R)
CH11: H2.3, J3.T
CH12: H2.4, J3.R

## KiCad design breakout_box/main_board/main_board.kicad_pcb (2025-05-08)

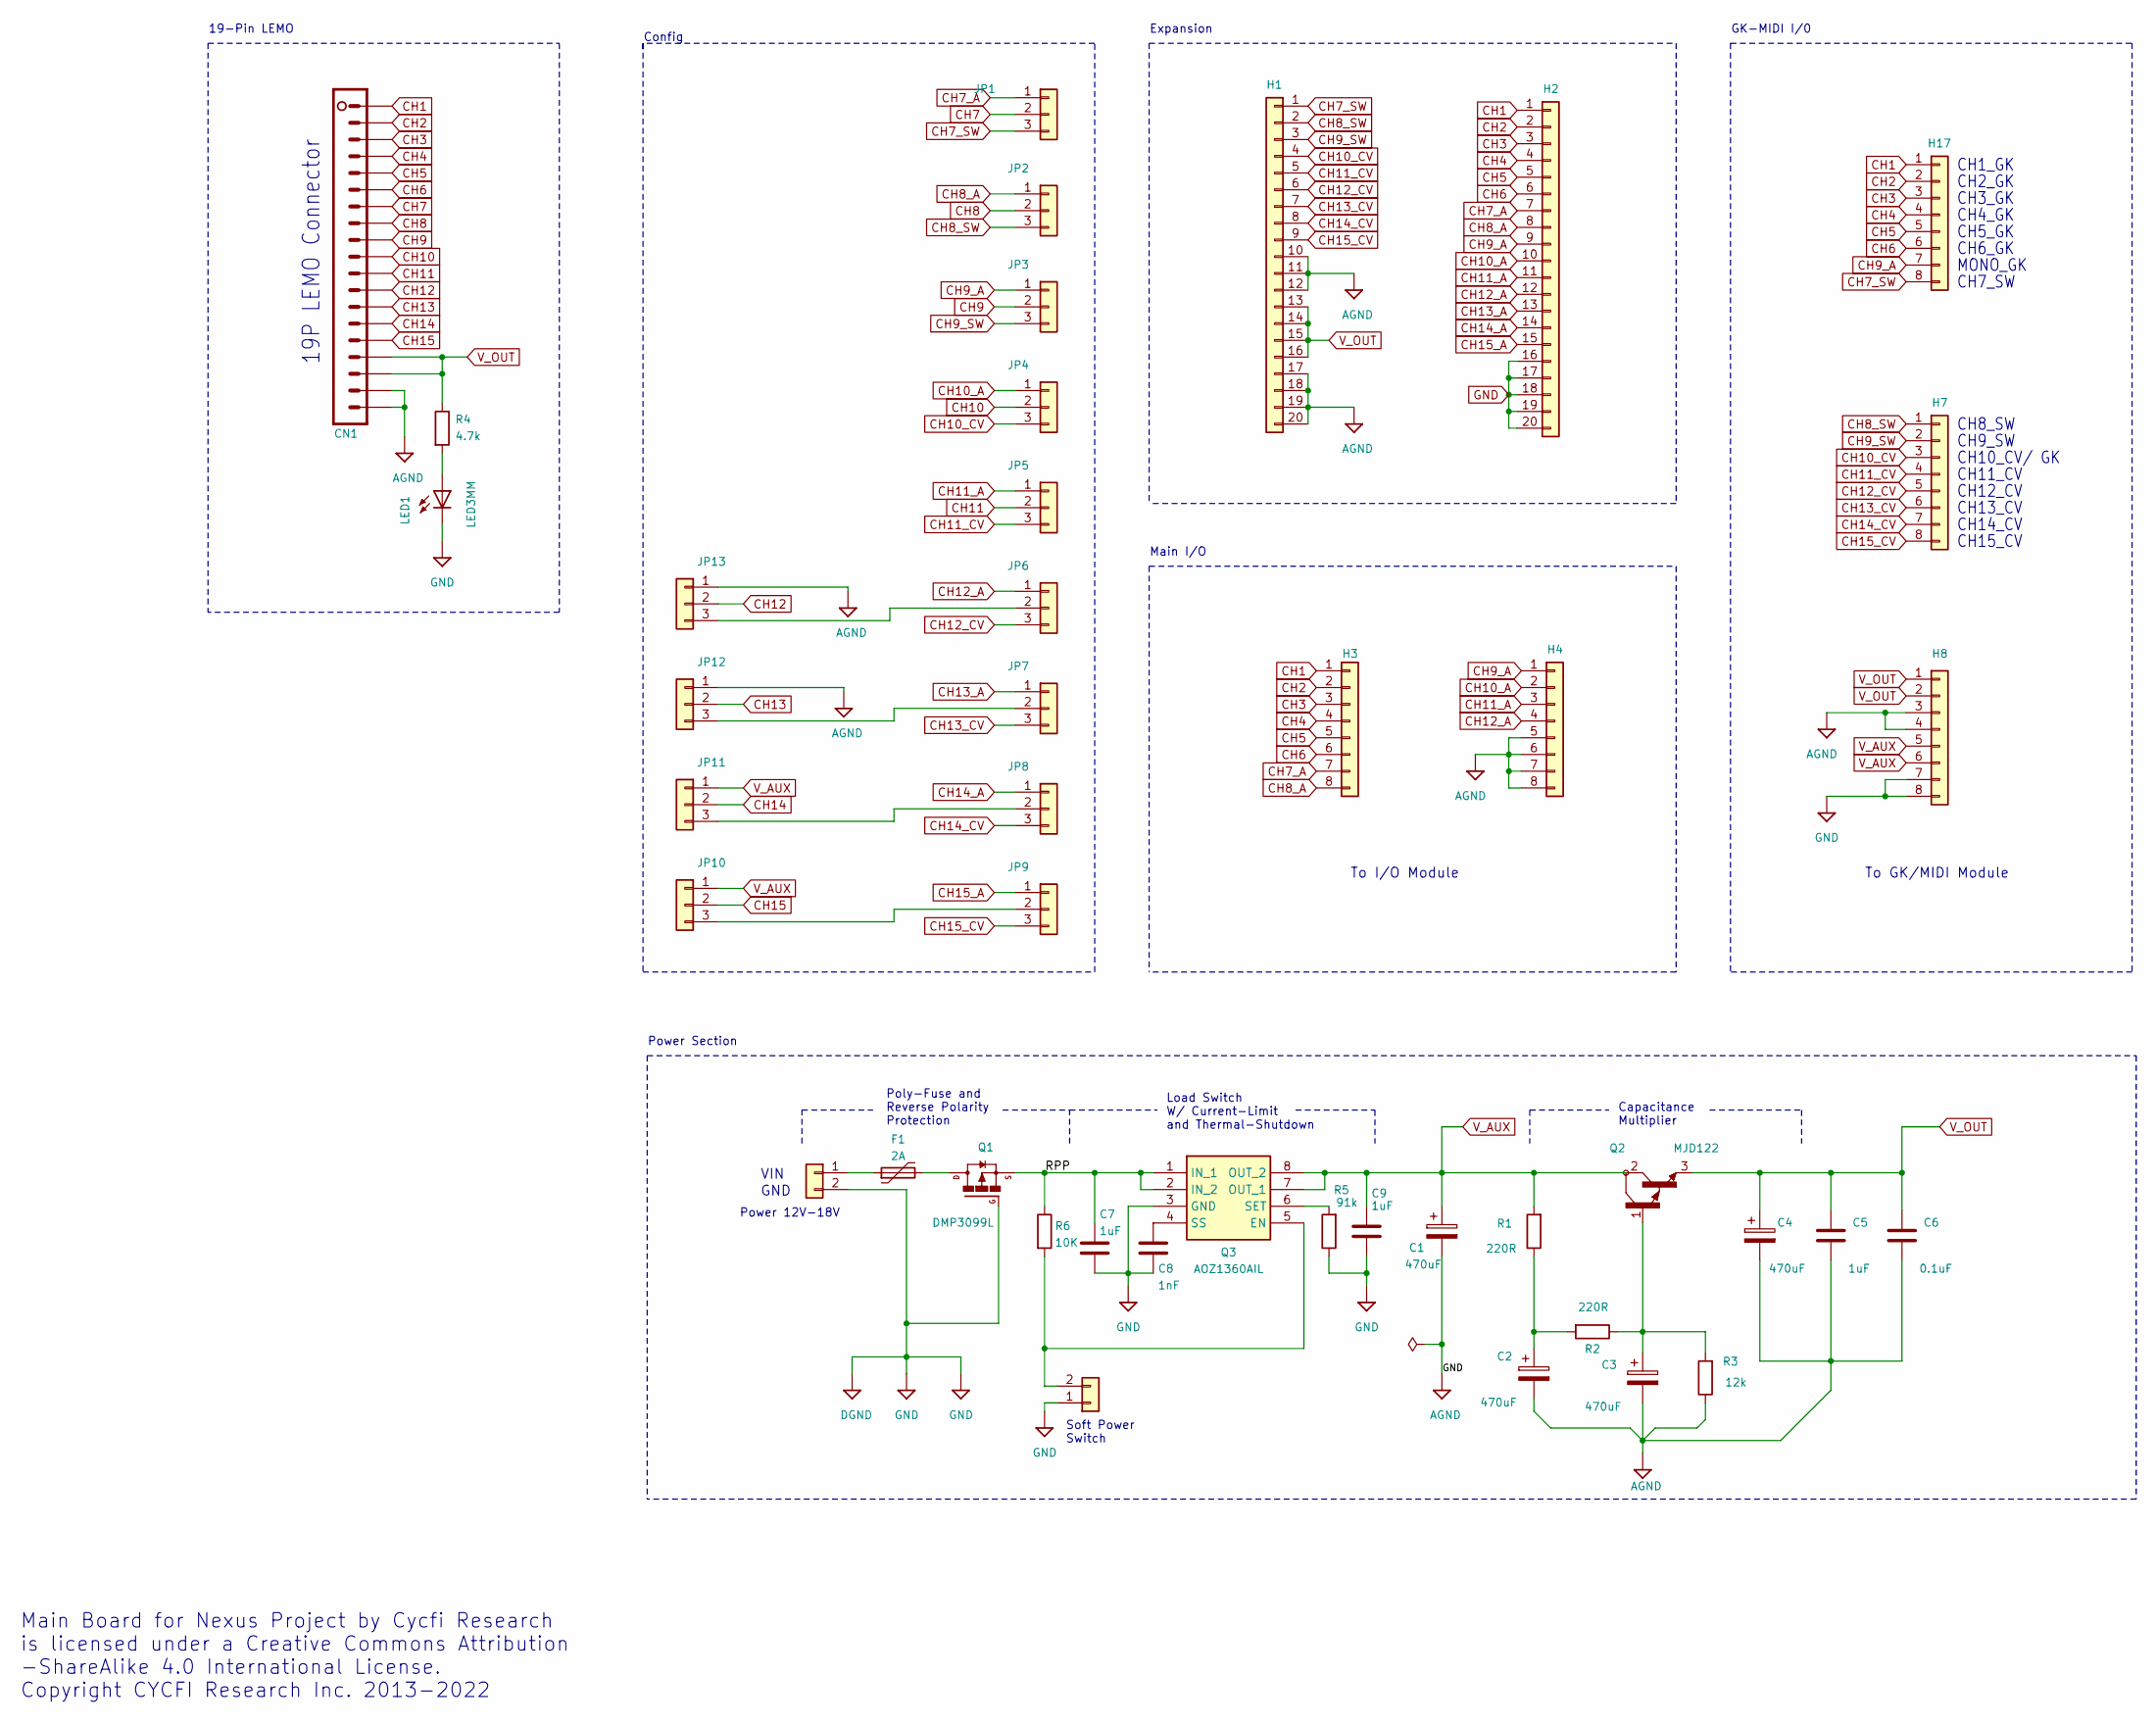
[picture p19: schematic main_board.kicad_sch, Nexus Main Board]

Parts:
C1, C2, C3, C4: 470uF; CP_Elec_10x10; LCSC C249933
C5, C7, C9: 1uF; C_0603_1608Metric; LCSC C15849
C6: 0.1uF; C_0603_1608Metric; LCSC C14663
C8: 1nF; C_0402_1005Metric; LCSC C1523
CN1: 19PIN_LEMO
F1: 2A; Fuse_1812_4532Metric; LCSC C883157
H1, H2: DNP; MA20-1
H3, H4, H7, H8, H17: MA08-1; PinHeader_1x08_P2.54mm_Vertical
H5: MA02-1; PinHeader_1x02_P2.54mm_Vertical
H6: MA02-1; PinHeader_1x02_P2.54mm_Horizontal
JP1, JP2, JP3, JP4, JP5, JP6, JP7, JP8, JP9, JP10, JP11, JP12, JP13: PINHD-1X03_2.00; 1X03M
LED1: LED3MM
Q1: DMP3099L; SOT-23; LCSC C2940610
Q2: MJD122; TO-252-2; LCSC C59488
Q3: AOZ1360AIL; SOIC127P600X175-8N; Manufacturer_Part_Number AOZ1360AIL; LCSC C146821
R1, R2: 220R; R_0603_1608Metric; LCSC C22962
R3: 12k; R_0603_1608Metric; LCSC C22790
R4: 4.7k; R_0805_2012Metric; LCSC C17673
R5: 91k; R_0603_1608Metric; LCSC C23265
R6: 10K; R_0402_1005Metric; LCSC C25744

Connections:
/RPP: C7.1, Q1.2 (S), Q3.1 (IN_1), Q3.2 (IN_2), R6.1
CH1: CN1.P$1 (1), H2.1, H3.1, H17.1
CH2: CN1.P$2 (2), H2.2, H3.2, H17.2
CH3: CN1.P$3 (3), H2.3, H3.3, H17.3
CH4: CN1.P$4 (4), H2.4, H3.4, H17.4
CH5: CN1.P$5 (5), H2.5, H3.5, H17.5
CH6: CN1.P$6 (6), H2.6, H3.6, H17.6
CH7: CN1.P$7 (7), JP1.2
CH7_A: H2.7, H3.7, JP1.1
CH7_SW: H1.1, H17.8, JP1.3
CH8: CN1.P$8 (8), JP2.2
CH8_A: H2.8, H3.8, JP2.1
CH8_SW: H1.2, H7.1, JP2.3
CH9: CN1.P$9 (9), JP3.2
CH9_A: H2.9, H4.1, H17.7, JP3.1
CH9_SW: H1.3, H7.2, JP3.3
CH10: CN1.P$10 (10), JP4.2
CH10_A: H2.10, H4.2, JP4.1
CH10_CV: H1.4, H7.3, JP4.3
CH11: CN1.P$11 (11), JP5.2
CH11_A: H2.11, H4.3, JP5.1
CH11_CV: H1.5, H7.4, JP5.3
CH12: CN1.P$12 (12), JP13.2
CH12_A: H2.12, H4.4, JP6.1
CH12_CV: H1.6, H7.5, JP6.3
CH13: CN1.P$13 (13), JP12.2
CH13_A: H2.13, JP7.1
CH13_CV: H1.7, H7.6, JP7.3
CH14: CN1.P$14 (14), JP11.2
CH14_A: H2.14, JP8.1
CH14_CV: H1.8, H7.7, JP8.3
CH15: CN1.P$15 (15), JP10.2
CH15_A: H2.15, JP9.1
CH15_CV: H1.9, H7.8, JP9.3
GND: C1.2, C2.2, C3.2, C4.2, C5.2, C6.2, C7.2, C8.2, C9.2, CN1.P$18 (18), CN1.P$19 (19), H1.10, H1.11, H1.12, H1.17, H1.18, H1.19, H1.20, H2.16, H2.17, H2.18, H2.19, H2.20, H4.5, H4.6, H4.7, H4.8, H5.1, H6.2, H8.3, H8.4, H8.7, H8.8, JP12.1, JP13.1, LED1.K (C), Q1.1 (G), Q3.3 (GND), R3.1, R5.1
unnamed: C2.1, R1.1, R2.2
unnamed: C3.1, Q2.1 (B), R2.1, R3.2
unnamed: C8.1, Q3.4 (SS)
unnamed: H5.2, Q3.5 (EN), R6.2
unnamed: F1.1, H6.1
unnamed: JP9.2, JP10.3
unnamed: JP8.2, JP11.3
unnamed: JP7.2, JP12.3
unnamed: JP6.2, JP13.3
unnamed: LED1.A, R4.2
unnamed: F1.2, Q1.3 (D)
unnamed: Q3.6 (SET), R5.2
V_AUX: C1.1, C9.1, H8.5, H8.6, JP10.1, JP11.1, Q2.2 (C), Q3.7 (OUT_1), Q3.8 (OUT_2), R1.2
V_OUT: C4.1, C5.1, C6.1, CN1.P$16 (16), CN1.P$17 (17), H1.13, H1.14, H1.15, H1.16, H8.1, H8.2, Q2.3 (E), R4.1

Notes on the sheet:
CH10_CV/ GK
CH3_GK
Main I/O
CH15_CV
To I/O Module
GK-MIDI I/0
Load Switch W/ Current-Limit and Thermal-Shutdown
CH12_CV
CH8_SW
Expansion
CH4_GK
CH7_SW
19-Pin LEMO
Power 12V-18V
CH13_CV
Capacitance Multiplier
CH14_CV
CH1_GK
CH5_GK
19P LEMO Connector
GND
CH6_GK
MONO_GK
CH11_CV
CH2_GK
Poly-Fuse and Reverse Polarity Protection
Main Board for Nexus Project by Cycfi Research is licensed under a Creative Commons Attribution -ShareAlike 4.0 International License. Copyright CYCFI Research Inc. 2013-2022
To GK/MIDI Module
CH9_SW
Soft Power Switch
VIN
Power Section
Config

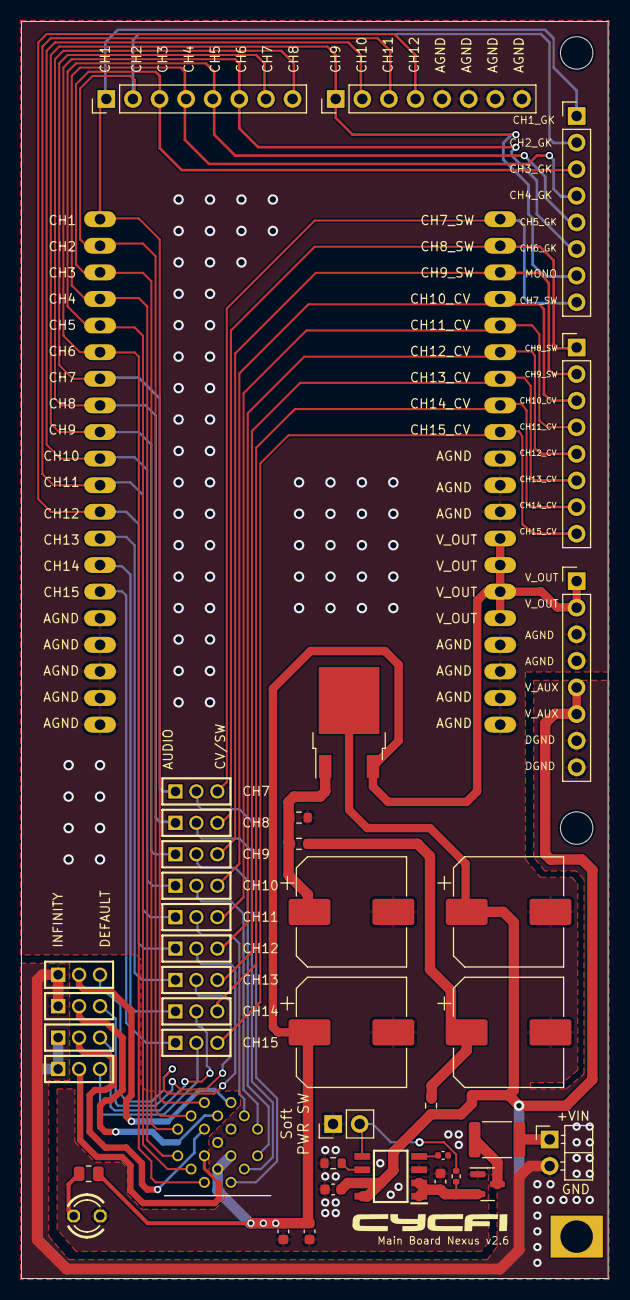
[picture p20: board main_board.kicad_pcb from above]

Board: 2 copper layers, 56.0 x 120.0 mm, 46 parts (0 on the bottom side), 49 nets.

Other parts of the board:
@HOLE0, @HOLE0#2: (no value)
GND_HOLE: (no value)

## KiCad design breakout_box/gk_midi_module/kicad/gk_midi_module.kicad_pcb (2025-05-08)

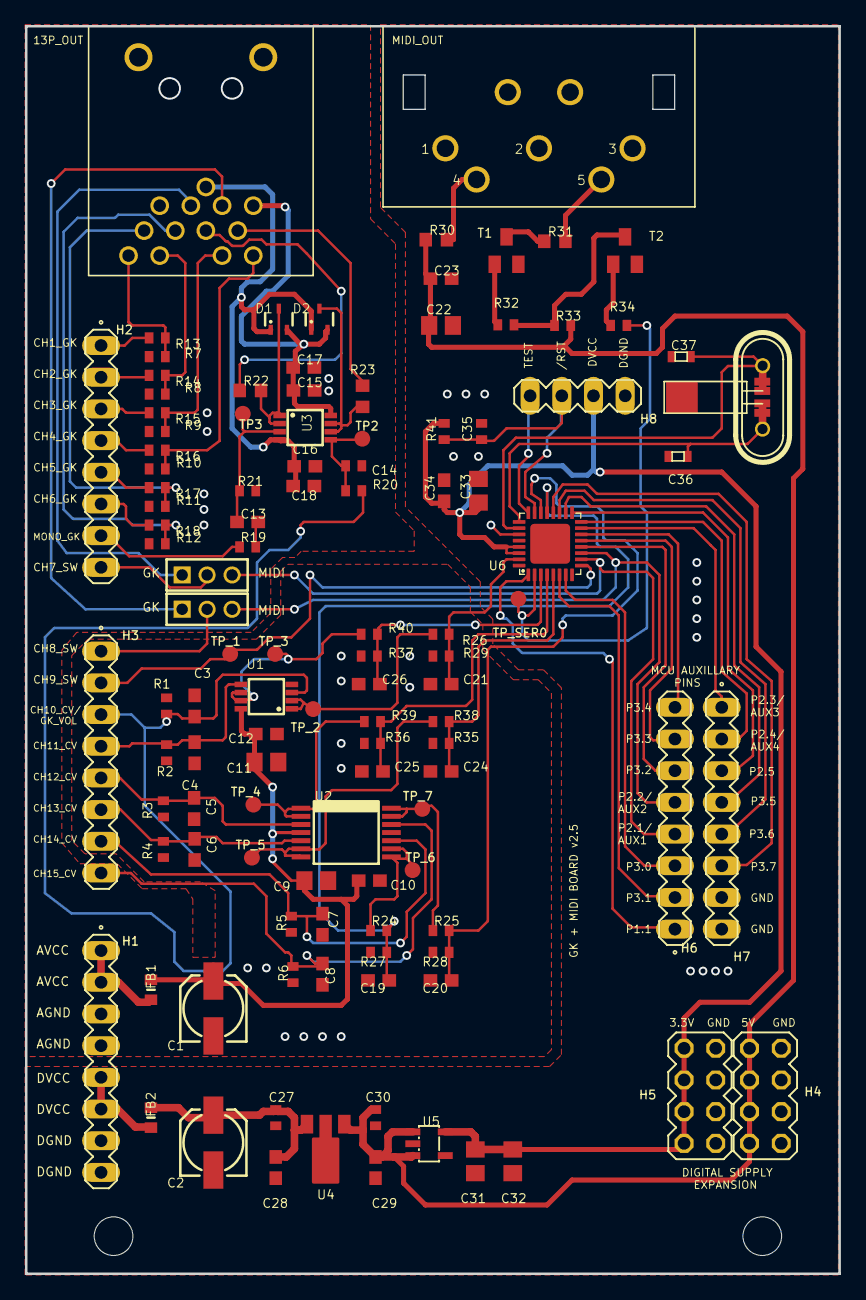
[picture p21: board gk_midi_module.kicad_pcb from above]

Board: 2 copper layers, 65.2 x 100.0 mm, 115 parts (0 on the bottom side), 77 nets.

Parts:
@HOLE0, @HOLE1: (no value)
C1, C2: 100uF; 153CLV-0505
C3, C4, C5, C6, C7, C8, C10, C12, C17, C18, C19, C20, C21, C23, C24, C25, C26, C28, C29: 0.1uF; C0603
C9, C11, C22: 10uF; C0805
C13: 0.47uF; C0603
C14: 0.01uF; C0402
C15, C16: 4.7uF; C0603
C27, C30: 1uF; C0402
C31: 33uf; C0805
C32: 10uf; C0805
C33: 2.2uf; C0805
C34: 0.1uf; C0603
C35: 1nF; C0402
C36, C37: 12pF; 0603
D1, D2: 1SS302; SC70-3
FB1, FB2: BLM18KG700TN1D; BEADC1608X75N
H1, H2, H3: MA08-1
H4, H5: DNP; MA04-2
H6, H7: DNP; MA08-1
H8: MA04-1
JP2, JP3: 1X03M
MIDI1: MIDI_JACK
R1, R2, R3, R4, R5, R6: 100K; R0402
R7, R8, R9, R10, R11, R12, R13, R14, R15, R16, R17, R18, R24, R25, R26, R38, R39, R40: 5.1k; R0402
R19: 10K; R0402
R20: 18K; R0402
R21: 470K; R0402
R22, R23: 100R; R0603
R27, R28, R29, R35, R36, R37: 10k; R0402
R30, R31: 220; R0603
R32, R33, R34: 1K; R0402
R41: 47K; R0402
T1, T2: 2N2222; SOT23-3
TP2, TP3: TPB1,27; B1,27
TP_1, TP_2, TP_3, TP_4, TP_5, TP_6, TP_7: TPB1,27; B1,27
TP_SER0: TPB1,27; B1,27
U1: MSOP8
U2: LMV324; SSOP-14
U3: TLV2170DGKT; MSOP8
U4: L78LXX; SOT89
U5: MIC5205-3.3; SOT23-5
U6: MSP430G2553RHB32; QFN32
U$1: 13P_MIDI_2; 13P-MIDI-2
X1: QUARZ5

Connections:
+3.3V: C31.1, C32.1, C33.1, C34.1, H5.2, H5.4, H5.6, H5.8, H8.3, R41.1, U5.5, U6.29, U6.30
+5V: C22.1, C23.1, C29.1, C30.1, H4.2, H4.4, H4.6, H4.8, R30.1, R33.2, U4.1, U5.1, U5.3
+VE: C15.1, C17.1, D1.2, D2.2, U3.8, U$1.12
-VE: C16.2, C18.2, D1.1, D2.1, U3.4, U$1.13
AVCC: FB1.1, H1.1, H1.2
CH1_GK: H2.1, R7.2
CH2_GK: H2.2, R8.2
CH3_GK: H2.3, R9.2
CH4_GK: H2.4, R10.2
CH5_GK: H2.5, R11.2
CH6_GK: H2.6, R12.2
CH7_GK_SW: JP2.1, U$1.10
CH7_GK_SW/CV: H2.8, JP2.2
CH7_MIDI_SW: H6.4, JP2.3, U6.10
CH8_GK_SW: JP3.1, U$1.11
CH8_GK_SW/CV: H3.1, JP3.2
CH8_MIDI_SW: H6.5, JP3.3, U6.11
CH9_SW: H3.2, TP_1.TP, U6.9
CH10_CV: R26.1, TP_2.TP, U1.1, U1.2
CH10_GK_VOL: C3.1, H3.3, R1.2, R20.1, U1.3
CH11_CV: R40.2, TP_3.TP, U1.6, U1.7
CH12_CV: R39.2, TP_4.TP, U2.1, U2.2
CH13_CV: R38.2, TP_5.TP, U2.6, U2.7
CH14_CV: R24.1, TP_6.TP, U2.8, U2.9
CH15_CV: R25.1, TP_7.TP, U2.13, U2.14
CH15_CV_IN: C8.1, H3.8, R6.2, U2.12
DVCC: FB2.1, H1.5, H1.6
D_VIN: C2.+, C27.1, C28.1, FB2.2, U4.3
GK_VOL: R23.2, U$1.8
GND: C1.-, C2.-, C3.2, C4.2, C5.2, C6.2, C7.2, C8.2, C9.2, C10.2, C11.2, C12.2, C14.2, C15.2, C16.1, C17.2, C18.1, C19.2, C20.2, C21.2, C22.2, C23.2, C24.2, C25.2, C26.2, C27.2, C28.2, C29.2, C30.2, C31.2, C32.2, C33.2, C34.2, C35.2, C36.1, C37.1, H1.3, H1.4, H1.7, H1.8, H4.1, H4.3, H4.5, H4.7, H5.1, H5.3, H5.5, H5.7, H7.7, H7.8, H8.4, MIDI1.2, MIDI1.G1, MIDI1.G2, R1.1, R2.1, R3.1, R4.1, R5.1, R6.1, R13.1, R14.1, R15.1, R16.1, R17.1, R18.1, R21.2, R27.2, R28.2, R29.2, R35.2, R36.2, R37.2, T1.2, T2.2, U1.4, U2.11, U4.2, U4.2@1, U5.2, U6.27, U6.28, U$1.P$1, U$1.P$2, X1.GND@0
MONO_GK: H2.7, R19.1
unnamed: MIDI1.5, R31.2
unnamed: R31.1, T1.3
unnamed: R32.2, T1.1
unnamed: MIDI1.4, R30.2
unnamed: R34.2, T2.1
unnamed: R32.1, R33.1, T2.3
unnamed: C4.1, H3.4, R2.2, U1.5
unnamed: C5.1, H3.5, R3.2, U2.3
unnamed: C6.1, H3.6, R4.2, U2.5
unnamed: C7.1, H3.7, R5.2, U2.10
unnamed: R22.1, U$1.7
unnamed: D2.3, R23.1, U3.6, U3.7
unnamed: C14.1, R20.2, TP2.TP, U3.5
unnamed: C13.2, R19.2
unnamed: C13.1, R21.1, TP3.TP, U3.3
unnamed: D1.3, R22.2, U3.1, U3.2
unnamed: R7.1, R13.2, U$1.1
unnamed: R8.1, R14.2, U$1.2
unnamed: R9.1, R15.2, U$1.3
unnamed: R10.1, R16.2, U$1.4
unnamed: R11.1, R17.2, U$1.5
unnamed: R12.1, R18.2, U$1.6
P1.0: C21.1, R26.2, R29.1, U6.31
P1.1: H6.1, U6.1
P1.2: R34.1, TP_SER0.TP, U6.2
P1.3: C26.1, R37.1, R40.1, U6.3
P1.4: C25.1, R36.1, R39.1, U6.4
P1.5: C24.1, R35.1, R38.1, U6.5
P1.6: C19.1, R24.2, R27.1, U6.21
P1.7: C20.1, R25.2, R28.1, U6.22
P2.3: H7.1, U6.15
P2.4: H7.2, U6.16
P2.5: H7.3, U6.17
P2.6: C37.2, U6.26, X1.1
P2.7: C36.2, U6.25, X1.2
P3.0: H6.3, U6.7
P3.1: H6.2, U6.6
P3.2: H6.6, U6.12
P3.3: H6.7, U6.13
P3.4: H6.8, U6.14
P3.5: H7.4, U6.18
P3.6: H7.5, U6.19
P3.7: H7.6, U6.20
TEST: H8.1, U6.24
VIN: C1.+, C9.1, C10.1, C11.1, C12.1, FB1.2, U1.8, U2.4
~RST: C35.1, H8.2, R41.2, U6.23

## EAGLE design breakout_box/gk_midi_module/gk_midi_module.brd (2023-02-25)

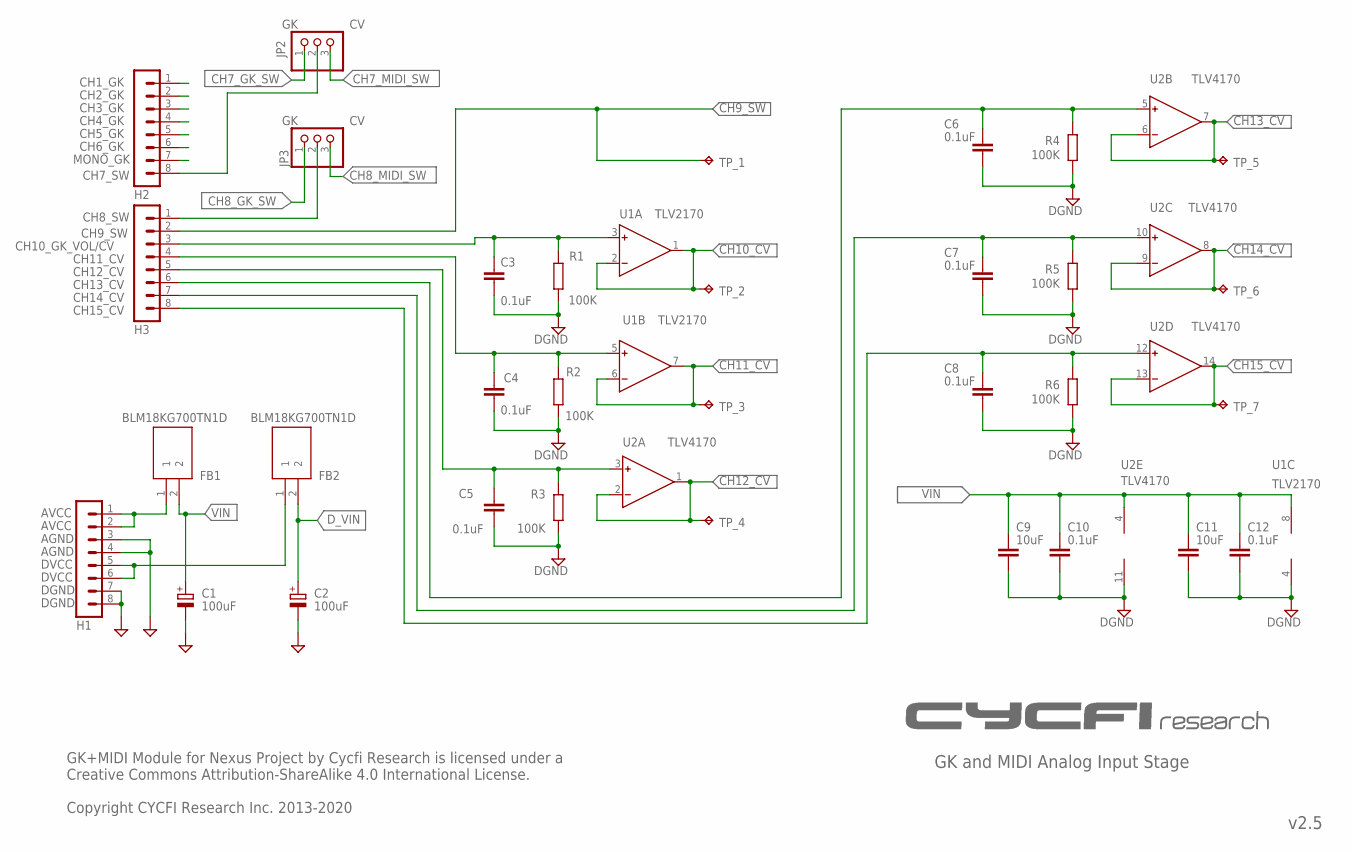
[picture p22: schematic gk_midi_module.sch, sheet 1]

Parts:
C1, C2: 100uF; 153CLV-0505
C3, C4, C5, C6, C7, C8, C10, C12: 0.1uF; C0603
C9, C11: 10uF; C0805
FB1: BLM18KG700TN1D; BEADC1608X75N
FB2: BLM18KG700TN1D; BEADC1608X75N; MANUFACTURER_PART_NUMBER BLM18KG700TN1D; MOUSER_PART_NUMBER 81-BLM18KG700TN1D
H1, H2, H3: MA08-1
JP2, JP3: PINHD-1X03_2.00; 1X03M
R1, R2, R3, R4, R5, R6: 100K; R0402
TP_1, TP_2, TP_3, TP_4, TP_5, TP_6, TP_7: TPB1,27; B1,27
U1: TLV2170DGKT; MSOP8
U2: LMV324; SSOP-14

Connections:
AVCC: FB1.1, H1.1, H1.2
CH1_GK: H2.1; also elsewhere on the board
CH2_GK: H2.2; also elsewhere on the board
CH3_GK: H2.3; also elsewhere on the board
CH4_GK: H2.4; also elsewhere on the board
CH5_GK: H2.5; also elsewhere on the board
CH6_GK: H2.6; also elsewhere on the board
CH7_GK_SW: JP2.1; also elsewhere on the board
CH7_GK_SW/CV: H2.8, JP2.2
CH7_MIDI_SW: JP2.3; also elsewhere on the board
CH8_GK_SW: JP3.1; also elsewhere on the board
CH8_GK_SW/CV: H3.1, JP3.2
CH8_MIDI_SW: JP3.3; also elsewhere on the board
CH9_SW: H3.2, TP_1.TP; also elsewhere on the board
CH10_CV: TP_2.TP, U1.1 (OUT), U1.2 (IN-); also elsewhere on the board
CH10_GK_VOL: C3.1, H3.3, R1.2, U1.3 (IN+); also elsewhere on the board
CH11_CV: TP_3.TP, U1.6 (IN-), U1.7 (OUT); also elsewhere on the board
CH12_CV: TP_4.TP, U2.1 (OUT), U2.2 (IN-); also elsewhere on the board
CH13_CV: TP_5.TP, U2.6 (IN-), U2.7 (OUT); also elsewhere on the board
CH14_CV: TP_6.TP, U2.8 (OUT), U2.9 (IN-); also elsewhere on the board
CH15_CV: TP_7.TP, U2.13 (IN-), U2.14 (OUT); also elsewhere on the board
CH15_CV_IN: C8.1, H3.8, R6.2, U2.12 (IN+)
DVCC: FB2.1, H1.5, H1.6
D_VIN: C2.+, FB2.2; also elsewhere on the board
GND: C1.-, C2.-, C3.2, C4.2, C5.2, C6.2, C7.2, C8.2, C9.2, C10.2, C11.2, C12.2, H1.3, H1.4, H1.7, H1.8, R1.1, R2.1, R3.1, R4.1, R5.1, R6.1, U1.4 (V-), U2.11 (V-); also elsewhere on the board
MONO_GK: H2.7; also elsewhere on the board
unnamed: C4.1, H3.4, R2.2, U1.5 (IN+)
unnamed: C5.1, H3.5, R3.2, U2.3 (IN+)
unnamed: C6.1, H3.6, R4.2, U2.5 (IN+)
unnamed: C7.1, H3.7, R5.2, U2.10 (IN+)
VIN: C1.+, C9.1, C10.1, C11.1, C12.1, FB1.2, U1.8 (V+), U2.4 (V+)

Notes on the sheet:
GK and MIDI Analog Input Stage
v2.5
CH9_SW
CH10_GK_VOL/CV
CH11_CV
CH12_CV
CH13_CV
CH14_CV
CH15_CV
DGND
AGND
GK+MIDI Module for Nexus Project by Cycfi Research is licensed under a Creative Commons Attribution-ShareAlike 4.0 International License. Copyright CYCFI Research Inc. 2013-2020
TLV4170
CH1_GK
CH2_GK
CH3_GK
CH4_GK
CH5_GK
CH6_GK
CH7_SW
MONO_GK
CH8_SW
U1C
U1B
U1A
TLV2170
U2A
U2B
U2C
U2D
U2E

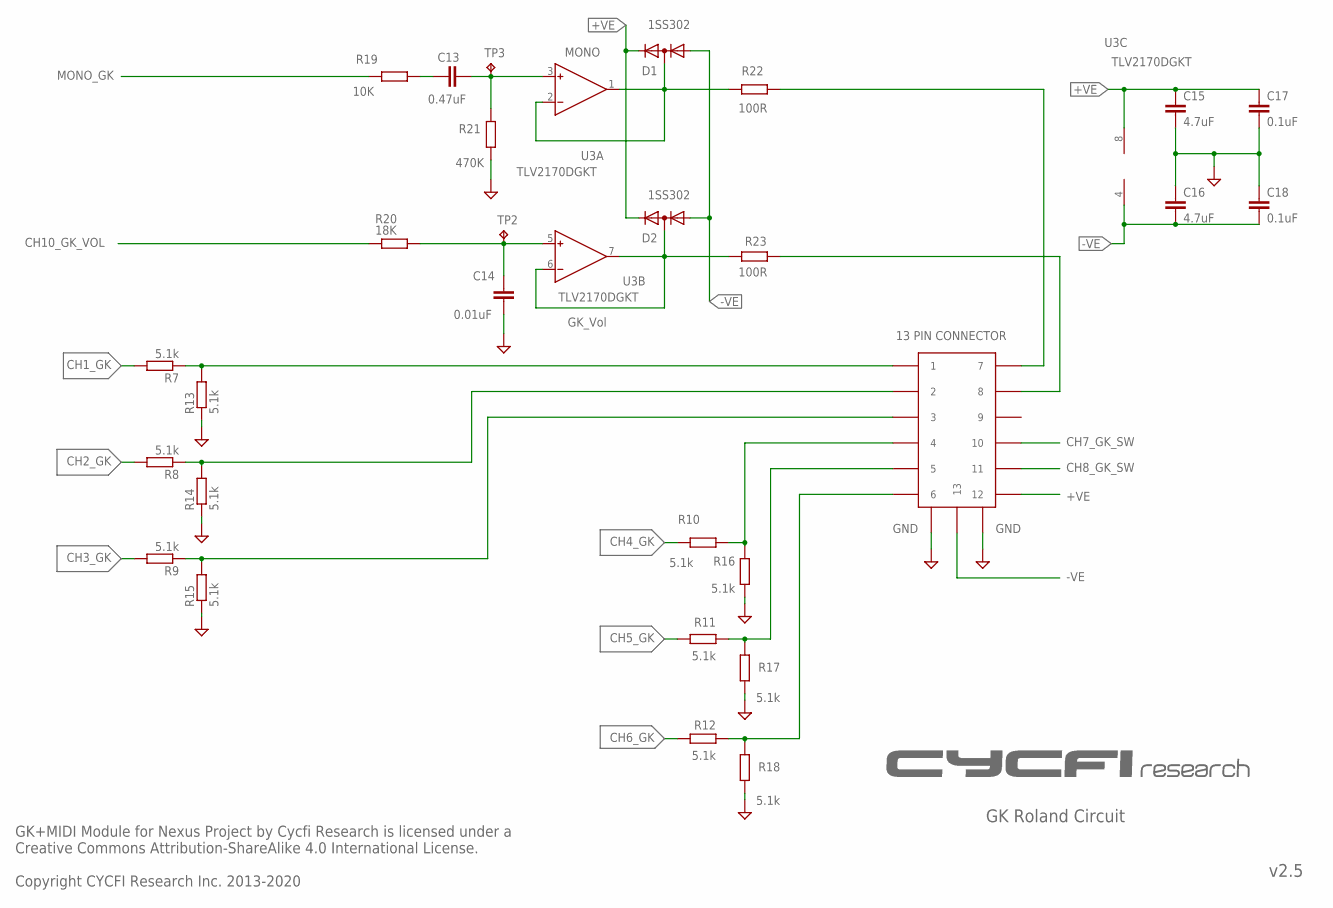
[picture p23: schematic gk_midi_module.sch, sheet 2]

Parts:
C13: 0.47uF; C0603
C14: 0.01uF; C0402
C15, C16: 4.7uF; C0603
C17, C18: 0.1uF; C0603
D1, D2: 1SS302; SC70-3
R7, R8, R9, R10, R11, R12, R13, R14, R15, R16, R17, R18: 5.1k; R0402
R19: 10K; R0402
R20: 18K; R0402
R21: 470K; R0402
R22, R23: 100R; R0603
TP2, TP3: TPB1,27; B1,27
U3: TLV2170DGKT; MSOP8
U$1: 13P_MIDI_2; 13P-MIDI-2

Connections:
+VE: C15.1, C17.1, D1.2 (K), D2.2 (K), U3.8 (V+), U$1.12
-VE: C16.2, C18.2, D1.1 (A), D2.1 (A), U3.4 (V-), U$1.13
CH1_GK: R7.2; also elsewhere on the board
CH2_GK: R8.2; also elsewhere on the board
CH3_GK: R9.2; also elsewhere on the board
CH4_GK: R10.2; also elsewhere on the board
CH5_GK: R11.2; also elsewhere on the board
CH6_GK: R12.2; also elsewhere on the board
CH7_GK_SW: U$1.10; also elsewhere on the board
CH8_GK_SW: U$1.11; also elsewhere on the board
CH10_GK_VOL: R20.1; also elsewhere on the board
GK_VOL: R23.2, U$1.8
GND: C14.2, C15.2, C16.1, C17.2, C18.1, R13.1, R14.1, R15.1, R16.1, R17.1, R18.1, R21.2, U$1.P$1 (14), U$1.P$2 (15); also elsewhere on the board
MONO_GK: R19.1; also elsewhere on the board
unnamed: R22.1, U$1.7
unnamed: D2.3 (AK), R23.1, U3.6 (IN-), U3.7 (OUT)
unnamed: C14.1, R20.2, TP2.TP, U3.5 (IN+)
unnamed: C13.2, R19.2
unnamed: C13.1, R21.1, TP3.TP, U3.3 (IN+)
unnamed: D1.3 (AK), R22.2, U3.1 (OUT), U3.2 (IN-)
unnamed: R7.1, R13.2, U$1.1
unnamed: R8.1, R14.2, U$1.2
unnamed: R9.1, R15.2, U$1.3
unnamed: R10.1, R16.2, U$1.4
unnamed: R11.1, R17.2, U$1.5
unnamed: R12.1, R18.2, U$1.6

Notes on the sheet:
GK Roland Circuit
MONO
GK_Vol
v2.5
GK+MIDI Module for Nexus Project by Cycfi Research is licensed under a Creative Commons Attribution-ShareAlike 4.0 International License. Copyright CYCFI Research Inc. 2013-2020
U3A
U3B
U3C
13 PIN CONNECTOR

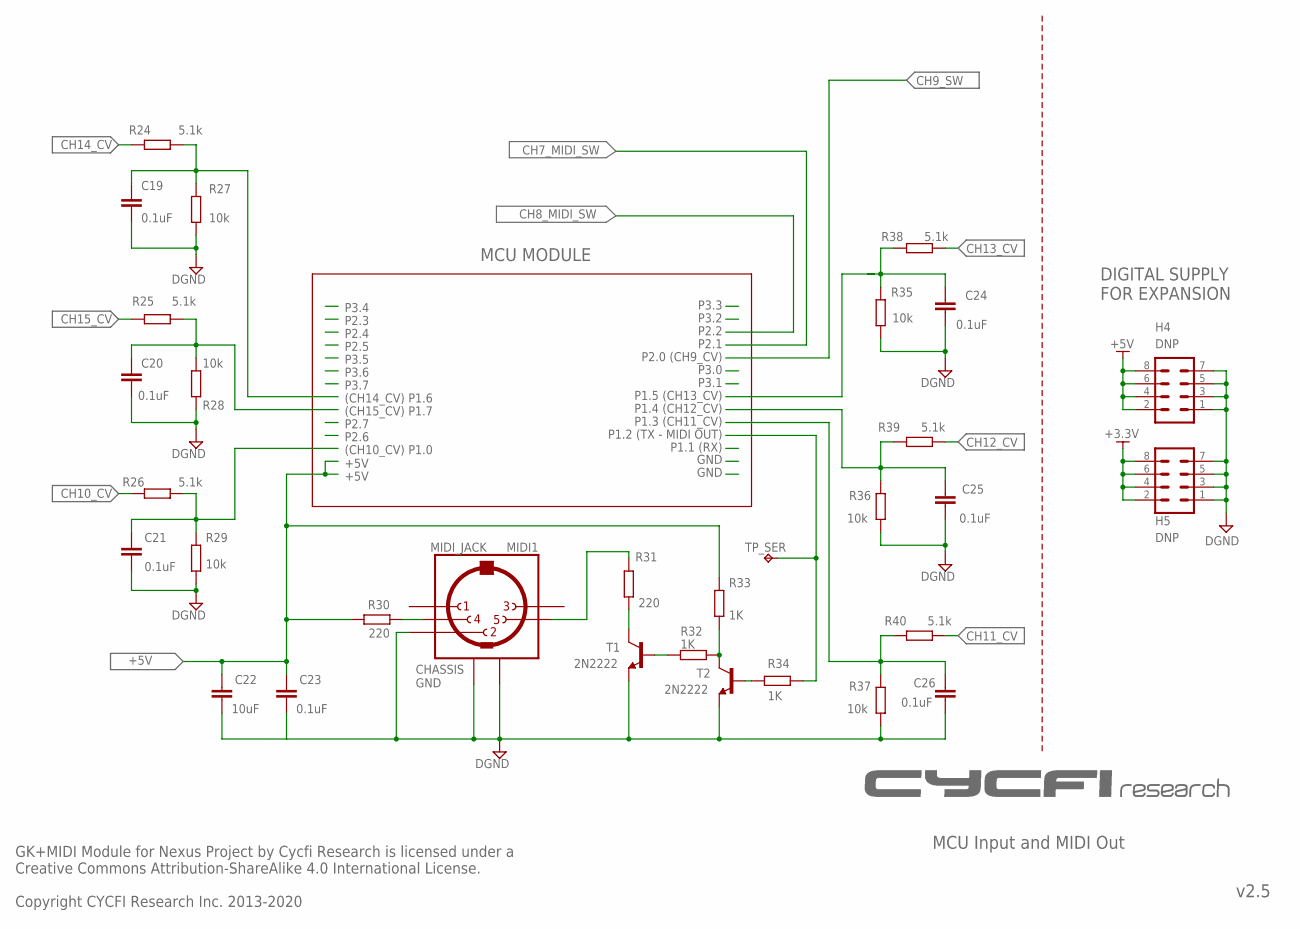
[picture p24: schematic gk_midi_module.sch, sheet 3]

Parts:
C19, C20, C21, C23, C24, C25, C26: 0.1uF; C0603
C22: 10uF; C0805
H4, H5: DNP; MA04-2
MIDI1: MIDI_JACK
R24, R25, R26, R38, R39, R40: 5.1k; R0402
R27, R28, R29, R35, R36, R37: 10k; R0402
R30, R31: 220; R0603
R32, R33, R34: 1K; R0402
T1, T2: 2N2222; SOT23-3
TP_SER: TPB1,27; B1,27

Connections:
+3.3V: H5.2, H5.4, H5.6, H5.8; also elsewhere on the board
+5V: C22.1, C23.1, H4.2, H4.4, H4.6, H4.8, R30.1, R33.2; also elsewhere on the board
CH10_CV: R26.1; also elsewhere on the board
CH11_CV: R40.2; also elsewhere on the board
CH12_CV: R39.2; also elsewhere on the board
CH13_CV: R38.2; also elsewhere on the board
CH14_CV: R24.1; also elsewhere on the board
CH15_CV: R25.1; also elsewhere on the board
GND: C19.2, C20.2, C21.2, C22.2, C23.2, C24.2, C25.2, C26.2, H4.1, H4.3, H4.5, H4.7, H5.1, H5.3, H5.5, H5.7, MIDI1.2, MIDI1.G1, MIDI1.G2, R27.2, R28.2, R29.2, R35.2, R36.2, R37.2, T1.2 (E), T2.2 (E); also elsewhere on the board
unnamed: MIDI1.5, R31.2
unnamed: R31.1, T1.3 (C)
unnamed: R32.2, T1.1 (B)
unnamed: MIDI1.4, R30.2
unnamed: R34.2, T2.1 (B)
unnamed: R32.1, R33.1, T2.3 (C)
P1.0: C21.1, R26.2, R29.1; also elsewhere on the board
P1.2: R34.1, TP_SER.TP; also elsewhere on the board
P1.3: C26.1, R37.1, R40.1; also elsewhere on the board
P1.4: C25.1, R36.1, R39.1; also elsewhere on the board
P1.5: C24.1, R35.1, R38.1; also elsewhere on the board
P1.6: C19.1, R24.2, R27.1; also elsewhere on the board
P1.7: C20.1, R25.2, R28.1; also elsewhere on the board

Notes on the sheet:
MCU Input and MIDI Out
v2.5
P3.3
P3.2
P2.2
P2.1
P2.0 (CH9_CV)
P3.0
P3.1
P1.5 (CH13_CV)
P1.4 (CH12_CV)
P1.3 (CH11_CV)
P1.2 (TX - MIDI OUT)
P1.1 (RX)
P3.4
P2.3
P2.4
P2.5
P3.5
P3.6
P3.7
(CH14_CV) P1.6
(CH15_CV) P1.7
P2.7
P2.6
(CH10_CV) P1.0
MCU MODULE
CHASSIS GND
DIGITAL SUPPLY FOR EXPANSION
GK+MIDI Module for Nexus Project by Cycfi Research is licensed under a Creative Commons Attribution-ShareAlike 4.0 International License. Copyright CYCFI Research Inc. 2013-2020

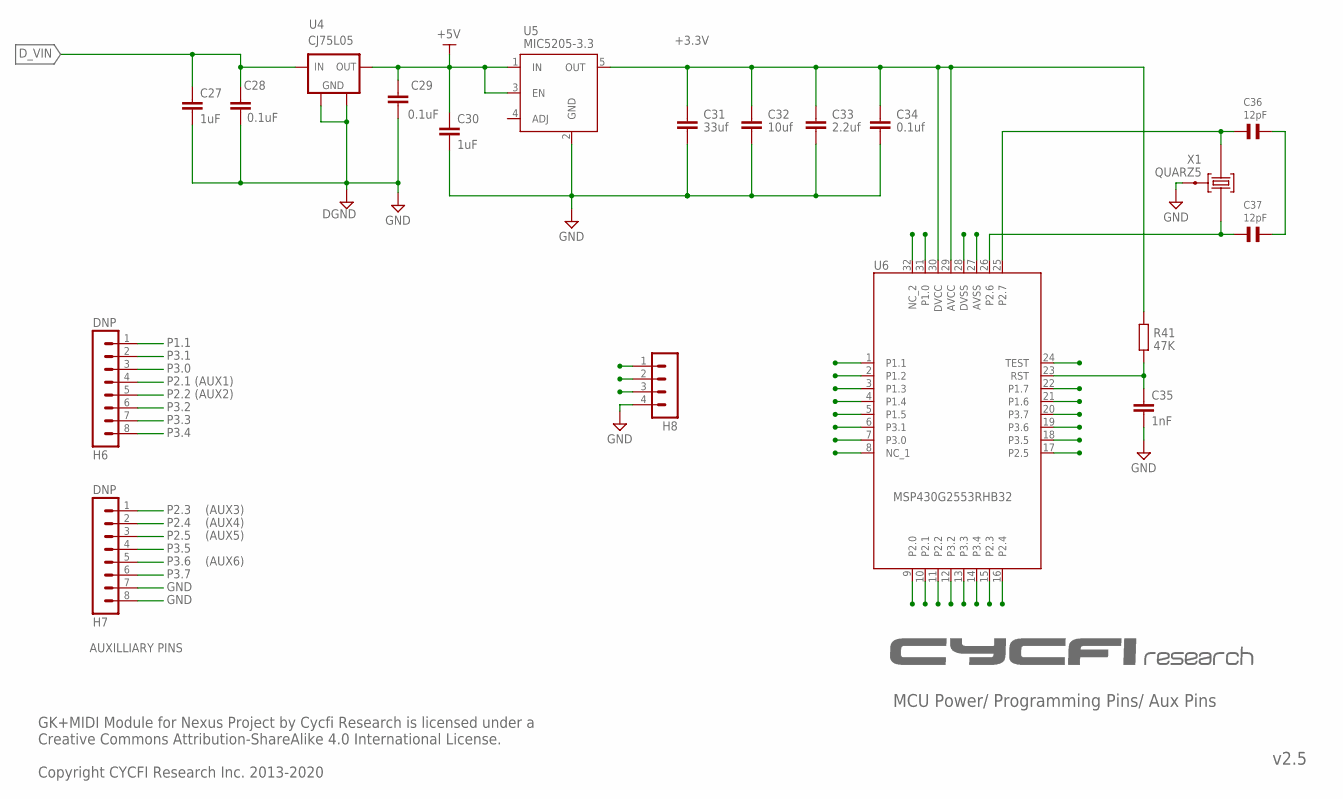
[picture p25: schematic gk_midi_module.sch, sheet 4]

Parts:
C27, C30: 1uF; C0402
C28, C29: 0.1uF; C0603
C31: 33uf; C0805
C32: 10uf; C0805
C33: 2.2uf; C0805
C34: 0.1uf; C0603
C35: 1nF; C0402
C36, C37: 12pF; 0603
H6, H7: DNP; MA08-1
H8: MA04-1
R41: 47K; R0402
U4: L78LXX; SOT89
U5: MIC5205-3.3; SOT23-5
U6: MSP430G2553RHB32; QFN32
X1: QUARZ5

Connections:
!RST: C35.1, H8.2, R41.2, U6.23 (RST)
+3.3V: C31.1, C32.1, C33.1, C34.1, H8.3, R41.1, U5.5 (OUT), U6.29 (AVCC), U6.30 (DVCC); also elsewhere on the board
+5V: C29.1, C30.1, U4.1 (IN), U5.1 (IN), U5.3 (EN); also elsewhere on the board
CH7_MIDI_SW: H6.4, U6.10 (P2.1); also elsewhere on the board
CH8_MIDI_SW: H6.5, U6.11 (P2.2); also elsewhere on the board
CH9_SW: U6.9 (P2.0); also elsewhere on the board
D_VIN: C27.1, C28.1, U4.3 (OUT); also elsewhere on the board
GND: C27.2, C28.2, C29.2, C30.2, C31.2, C32.2, C33.2, C34.2, C35.2, C36.1, C37.1, H7.7, H7.8, H8.4, U4.2 (GND), U4.2@1 (GND1), U5.2 (GND), U6.27 (AVSS), U6.28 (DVSS), X1.GND@0 (0); also elsewhere on the board
NC: U6.8 (NC_1)
P1.0: U6.31 (P1.0); also elsewhere on the board
P1.1: H6.1, U6.1 (P1.1)
P1.2: U6.2 (P1.2); also elsewhere on the board
P1.3: U6.3 (P1.3); also elsewhere on the board
P1.4: U6.4 (P1.4); also elsewhere on the board
P1.5: U6.5 (P1.5); also elsewhere on the board
P1.6: U6.21 (P1.6); also elsewhere on the board
P1.7: U6.22 (P1.7); also elsewhere on the board
P2.3: H7.1, U6.15 (P2.3)
P2.4: H7.2, U6.16 (P2.4)
P2.5: H7.3, U6.17 (P2.5)
P2.6: C37.2, U6.26 (P2.6), X1.1
P2.7: C36.2, U6.25 (P2.7), X1.2
P3.0: H6.3, U6.7 (P3.0)
P3.1: H6.2, U6.6 (P3.1)
P3.2: H6.6, U6.12 (P3.2)
P3.3: H6.7, U6.13 (P3.3)
P3.4: H6.8, U6.14 (P3.4)
P3.5: H7.4, U6.18 (P3.5)
P3.6: H7.5, U6.19 (P3.6)
P3.7: H7.6, U6.20 (P3.7)
TEST: H8.1, U6.24 (TEST)

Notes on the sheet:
MCU Power/ Programming Pins/ Aux Pins
v2.5
GK+MIDI Module for Nexus Project by Cycfi Research is licensed under a Creative Commons Attribution-ShareAlike 4.0 International License. Copyright CYCFI Research Inc. 2013-2020
CJ75L05
AUXILLIARY PINS
P2.1 (AUX1)
P2.2 (AUX2)
(AUX3)
(AUX4)
(AUX5)
(AUX6)

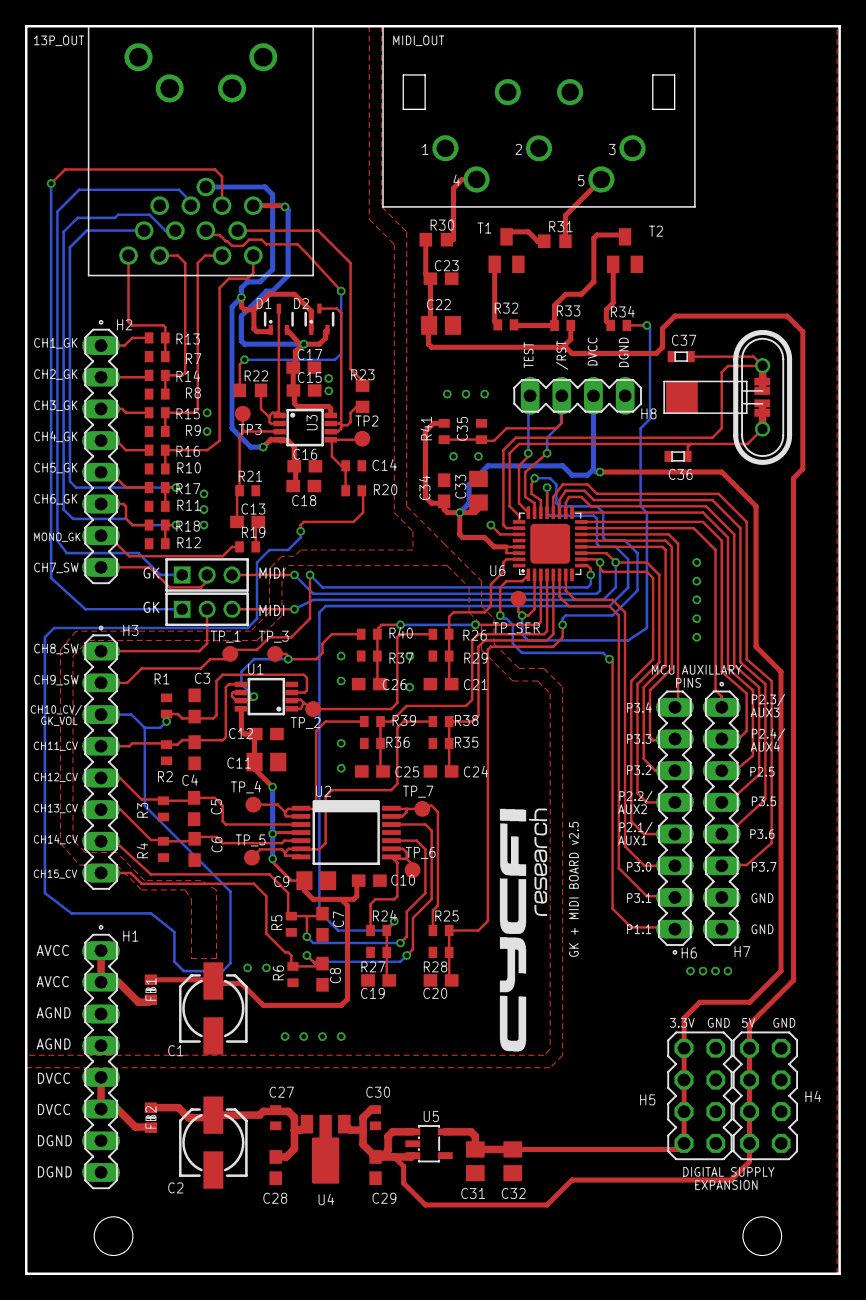
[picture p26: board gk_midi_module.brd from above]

Board: 2 copper layers, 65.2 x 100.0 mm, 113 parts (0 on the bottom side), 77 nets.

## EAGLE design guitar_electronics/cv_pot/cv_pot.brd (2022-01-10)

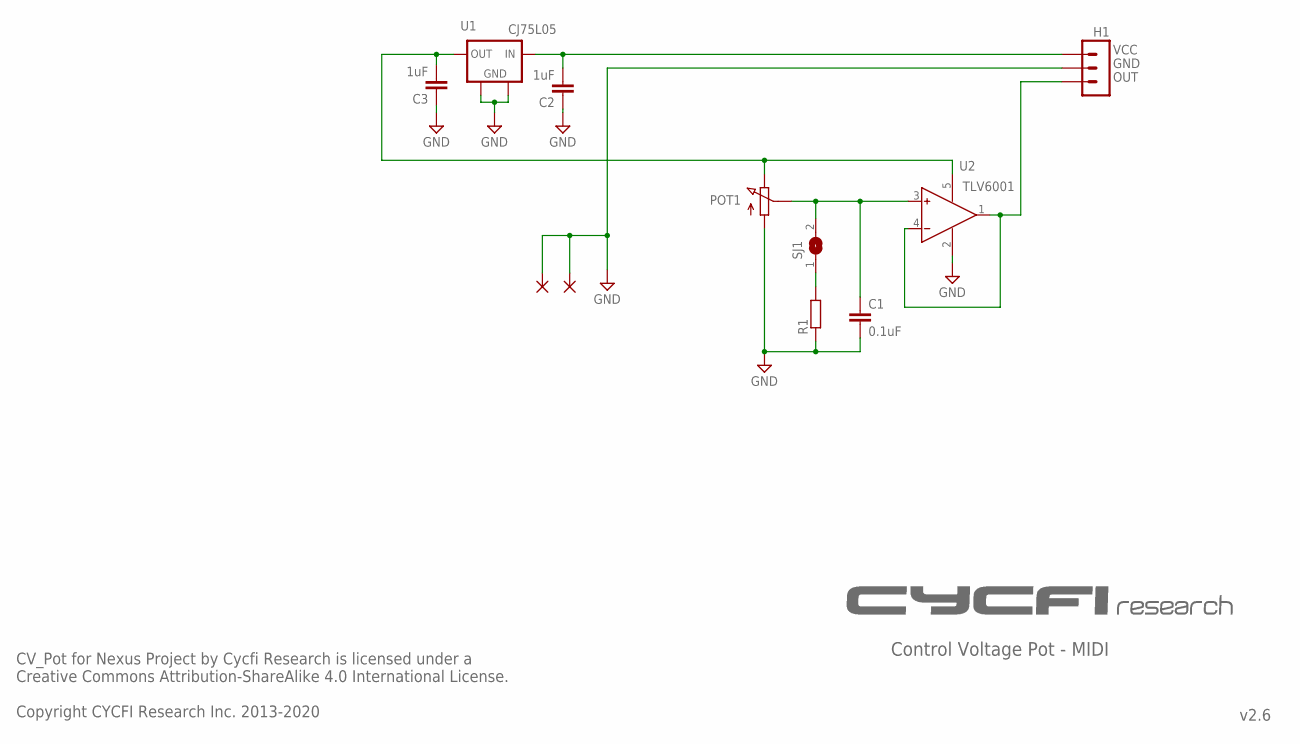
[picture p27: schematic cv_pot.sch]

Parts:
C1: 0.1uF; C0402
C2, C3: 1uF; C0603
GND1, GND2: SMD2; SMD1,27-2,54
H1: 3PIN-SMD-2.54MM; 3P-SMD-2.54MM
POT1: 25K; POT_EU_PDB181GTR
R1: R-EU_R0402; R0402
SJ1: SJ
U1: L78LXX; SOT89
U2: TLV6001; SOT23-5

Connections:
GND: C1.2, C2.1, C3.1, GND1.1, GND2.1, H1.P$2 (2), POT1.A1 (1), R1.1, U1.2 (GND), U1.2@1 (GND1), U2.2 (V-)
unnamed: C2.2, H1.P$3 (3), U1.3 (OUT)
unnamed: C3.2, POT1.A3 (3), U1.1 (IN), U2.5 (V+)
unnamed: C1.1, POT1.A2 (2), SJ1.2, U2.3 (IN+)
unnamed: R1.2, SJ1.1
unnamed: H1.P$1 (1), U2.1 (OUT), U2.4 (IN-)

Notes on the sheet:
Control Voltage Pot - MIDI
VCC
GND
OUT
v2.6
CV_Pot for Nexus Project by Cycfi Research is licensed under a Creative Commons Attribution-ShareAlike 4.0 International License. Copyright CYCFI Research Inc. 2013-2020
CJ75L05

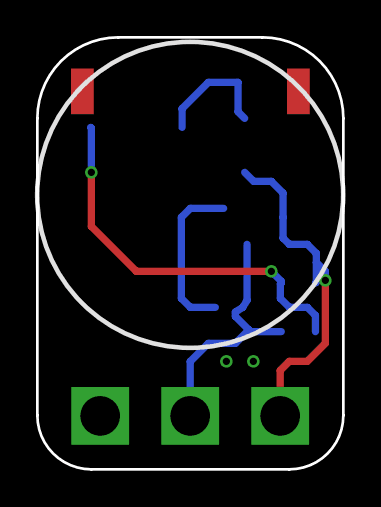
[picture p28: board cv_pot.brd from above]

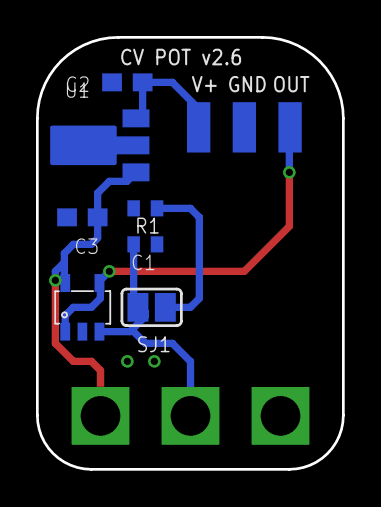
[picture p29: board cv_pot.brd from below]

Board: 2 copper layers, 17.0 x 24.0 mm, 11 parts (8 on the bottom side), 6 nets.

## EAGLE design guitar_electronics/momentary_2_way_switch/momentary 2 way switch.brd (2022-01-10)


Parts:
C1, C2: 10uF; C0603
D1, D2: CUS551V30,H3F; SOD-323
H1: 3PIN-SMD-2.54MM; 3P-SMD-2.54MM
R1, R2: 1K; R0402
S1: SPDT

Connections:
GND: C1.2, C2.2, H1.P$2 (2), S1.2
unnamed: C1.1, D1.2 (C), R1.2
unnamed: R1.1, S1.1 (O)
unnamed: C2.1, D2.2 (C), R2.2
unnamed: R2.1, S1.3 (S)
SW1: D2.1 (A), H1.P$3 (3)
SW2: D1.1 (A), H1.P$1 (1)

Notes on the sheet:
CV_Pot for Nexus Project by Cycfi Research is licensed under a Creative Commons Attribution-ShareAlike 4.0 International License. Copyright CYCFI Research Inc. 2013-2017
v2.5
CV Momentary Button
GND


Board: 2 copper layers, 15.0 x 17.0 mm, 8 parts (1 on the bottom side), 7 nets.

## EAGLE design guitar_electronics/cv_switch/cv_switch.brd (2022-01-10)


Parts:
C1, C2: 1uF; C0603
C3: 10uF; C0603
H1: MA03-1_EDITED; MA03-1_
R1, R4: 1.5K; R0402
R2: 3K; R0402
R3: 3k; R0402
U1: CJ75L05; SOT89
U$1: 5WAY_SW_1; 5WAY_SW_CASTELLATED

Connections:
+5V: C2.1, R1.2, R2.2, U1.1 (IN)
GND: C1.2, C2.2, C3.2, H1.2, R3.1, R4.1, U1.2 (GND), U1.2@1 (GND1)
unnamed: C1.1, H1.3, U1.3 (OUT)
unnamed: R4.2, U$1.B1
unnamed: R2.1, R3.2, U$1.M1
unnamed: R1.1, U$1.N1
OUT: C3.1, H1.1, U$1.COM1

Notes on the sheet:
VCC
GND
OUT
5Way Switch - Control Voltage
v2.5
CV Switch for Nexus Project by Cycfi Research is licensed under a Creative Commons Attribution-ShareAlike 4.0 International License. Copyright CYCFI Research Inc. 2013-2020
POSITION
OUTPUT
3.3V
2.5V
1.25V
0.0V
CJ75L05



Board: 2 copper layers, 51.0 x 24.5 mm, 10 parts (8 on the bottom side), 7 nets.

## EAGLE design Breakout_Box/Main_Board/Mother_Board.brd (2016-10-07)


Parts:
CN1: 19PIN_LEMO
H1, H2: MA20-1
H6, H7, H8, H9: MA08-1
H10, H11, H12, H13: MA03-1_EDITED; MA03-1_
LED1: LED3MM
R2: 4.7k; R0402

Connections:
+12V_REG: CN1.P$16 (16), H1.8, H1.9, H1.10, H1.11, H9.1, H9.2, H9.3, H9.4, R2.1; also elsewhere on the board
AGND: CN1.P$19 (19), H1.16, H1.17, H1.18, H1.19, H7.5, H7.6, H7.7, H7.8, LED1.K (C); also elsewhere on the board
DGND: H1.12, H1.13, H1.14, H1.15, H9.5, H9.6, H9.7, H9.8
unnamed: CN1.P$1 (1), H2.1, H6.1
unnamed: CN1.P$2 (2), H2.2, H6.2
unnamed: CN1.P$3 (3), H2.3, H6.3
unnamed: CN1.P$4 (4), H2.4, H6.4
unnamed: CN1.P$5 (5), H2.5, H6.5
unnamed: CN1.P$6 (6), H2.6, H6.6
unnamed: CN1.P$7 (7), H2.7, H6.7
unnamed: CN1.P$8 (8), H2.8, H6.8
unnamed: CN1.P$9 (9), H10.2
unnamed: CN1.P$10 (10), H11.2
unnamed: CN1.P$11 (11), H12.2
unnamed: CN1.P$12 (12), H13.2
unnamed: H2.10, H7.2, H11.1
unnamed: LED1.A, R2.2
unnamed: H2.12, H7.4, H13.1
unnamed: H2.11, H7.3, H12.1
unnamed: H2.9, H7.1, H10.1
unnamed: H1.1, H8.1, H10.3
unnamed: H1.2, H8.2, H11.3
unnamed: H1.3, H8.3, H12.3
unnamed: H1.4, H8.4, H13.3
unnamed: CN1.P$13 (13), H1.5, H8.5
unnamed: CN1.P$14 (14), H1.6, H8.6
unnamed: CN1.P$15 (15), H1.7, H8.7

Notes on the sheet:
Channel Distribution
v0.9
2016050
CH1
CH2
CH3
CH4
CH5
CH6
CH7
CH8
CH9_A
CH10_A
CH11_A
CH12_A
CH9_CV
CH10_CV
CH11_CV
CH12_CV
CH13_CV
CH14_CV
CH15_CV
AGND
From 19P LEMO Connector
To Stereo Jack
To MIDI Module
NOTE: *DGND = Digital Ground *AGND = Analog Ground *+12V_REG = 12V Regulated Power Supply
NOTE: *CH9_A = Channel9 Audio *CH9_CV = Channel9 Control Voltage *NC = No Connection
DGND
Nexus Project by Cycfi Research is licensed under a Creative Commons Attribution-NonCommercial 4.0 International License. http://creativecommons.org/licenses/by-nc/4.0/ Copyright CYCFI Research Inc. 2013-2016
CH9
CH10
CH11
CH12
CH13
CH14
CH15


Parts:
C2: 0.1uF; C0603
C6: 1000uF; 140CLH-1010
D1: FM4007W; SMX
H14: MA02-1
L1: 100uH; L1280

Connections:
+12V_REG: C2.1, C6.+, L1.P$2 (2); also elsewhere on the board
AGND: C2.2, C6.-, H14.1; also elsewhere on the board
unnamed: D1.ANODE (A), H14.2
unnamed: D1.CATHODE (C), L1.P$1 (1)

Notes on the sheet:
Main Power Source
NOTES: *+12V_REG = 12V Regulater Power Supply *AGND = Analog Ground *DGND= Digital Ground
v0.92
+12V IN
GND
Nexus Project by Cycfi Research is licensed under a Creative Commons Attribution-NonCommercial 4.0 International License. http://creativecommons.org/licenses/by-nc/4.0/ Copyright CYCFI Research Inc. 2013-2016
2016050


Board: 2 copper layers, 60.0 x 100.0 mm, 18 parts (0 on the bottom side), 29 nets.

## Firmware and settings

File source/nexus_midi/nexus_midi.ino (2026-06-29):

/*==============================================================================
    Copyright (c) 2016 Cycfi Research

    Distributed under the MIT License [ https://opensource.org/licenses/MIT ]
   ===========================================================================*/

#include "nexus_controls.hpp"

// Drive MIDI TX HIGH before global constructors. Device-only (pokes P1DIR).
#ifndef NEXUS_HOST
// Drive MIDI TX (P1.2) HIGH as early as possible — before global
// constructors and before setup(). The internal pull-up (~50kΩ) is too
// weak to overcome the MIDI output circuit (220Ω + LED), so we actively
// drive the pin HIGH as an output. Serial.begin() in midi_out.start() will
// reconfigure P1.2 as UART TX; while in UART reset (UCSWRST=1, the
// default at power-on), the UART peripheral holds TX HIGH, so the
// transition is glitch-free.
void __attribute__((naked, section(".init3"), used)) _midi_tx_drive_high()
{
   P1DIR |= BIT2;   // set P1.2 as output
   P1OUT |= BIT2;   // drive P1.2 HIGH (MIDI mark = idle)
}
#endif

using namespace cycfi;

// The main MIDI out stream.
midi::midi_stream midi_out;

// We use SEGMENT_B and SEGMENT_C to store program change and bank select
// data.
flash flash_b(SEGMENT_B);
flash flash_c(SEGMENT_C);

// Save delay: We lazily save data to flash to minimize writes to flash
// and thus conserve erase cycles. To do this, we avoid eagerly saving
// data when the user is actively changing states (e.g. buttons are pushed).
// We delay the actual save N milliseconds after the last state change.

uint32_t const save_delay = 3000;  // 3 seconds delay
int32_t save_delay_start_time = -1;

void reset_save_delay()
{
   save_delay_start_time = millis();
}

// Timestamp of the last CC send. Used by pitch_bend_controller to
// raise its gate threshold during CC activity, suppressing crosstalk.
uint32_t last_cc_time = 0;

////////////////////////////////////////////////////////////////////////////////
// The controls
////////////////////////////////////////////////////////////////////////////////
controller<midi::cc::channel_volume>   volume_control;
controller<midi::cc::effect_1>         fx1_control;
controller<midi::cc::effect_2>         fx2_control;
controller<midi::cc::modulation>       modulation_control;
pitch_bend_controller                  pitch_bend;
program_change_controller              program_change;
sustain_controller                     sustain_control;
bank_select_controller                 bank_select_control;

////////////////////////////////////////////////////////////////////////////////
// setup
////////////////////////////////////////////////////////////////////////////////
void setup()
{
   midi_out.start();
   midi_out << uint8_t(0xFF);

   pinMode(ch9 , INPUT_PULLUP);
   pinMode(ch10, INPUT);
   pinMode(ch11, INPUT);
   pinMode(ch12, INPUT);
   pinMode(ch13, INPUT);
   pinMode(ch14, INPUT);
   pinMode(ch15, INPUT);

   pinMode(aux1, INPUT_PULLUP);
   pinMode(aux2, INPUT_PULLUP);
   pinMode(aux3, INPUT_PULLUP);
   pinMode(aux4, INPUT_PULLUP);
   pinMode(aux5, INPUT_PULLUP);
   pinMode(aux6, INPUT_PULLUP);

   // Start the background ADC oversampler before any analog read (it fills
   // the per-channel values during the flash load / transmit below, no-op on
   // host).
   adc::start();

   // Load the program_change and bank_select_control states from flash
   program_change.load();
   bank_select_control.load();

   program_change.transmit();
   bank_select_control.transmit();

   // Prime controller filters from the live hardware state so the first loop
   // iteration does not ramp from zero. Each init() also transmits the
   // seeded startup state.
   sustain_control.init(digitalRead(ch9));
   volume_control.init(analog_read(ch10));
   fx1_control.init(analog_read(ch11));
   fx2_control.init(analog_read(ch12));
   pitch_bend.init(ch13);
   modulation_control.init(analog_read(ch15));

}

uint32_t prev_time = 0;

void loop()
{
   // Wish we used timer interrupts. Anyway, at least make sure we don't
   // exceed a 1kHz processing loop.
   if (prev_time != millis())
   {
      sustain_control(digitalRead(ch9));
      volume_control(analog_read(ch10));
      fx1_control(analog_read(ch11));
      fx2_control(analog_read(ch12));
      pitch_bend();
      program_change(analog_read(ch14));
      modulation_control(analog_read(ch15));

      program_change.up(!digitalRead(aux1));
      program_change.down(!digitalRead(aux2));
      program_change.group_up(!digitalRead(aux3));
      program_change.group_down(!digitalRead(aux4));
      bank_select_control.up(!digitalRead(aux5));
      bank_select_control.down(!digitalRead(aux6));

      prev_time = millis();
   }

   // Save the program_change and bank_select_control if needed
   if ((save_delay_start_time != -1)
      && (millis() > (save_delay_start_time + save_delay)))
   {
      program_change.save();
      bank_select_control.save();
      save_delay_start_time = -1;
   }
}

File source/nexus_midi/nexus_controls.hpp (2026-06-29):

/*==============================================================================
    Copyright (c) 2016 Cycfi Research

    Distributed under the MIT License [ https://opensource.org/licenses/MIT ]
   ===========================================================================*/

#if !defined(CYCFI_NEXUS_CONTROLS_HPP_JUNE_25_2026)
#define CYCFI_NEXUS_CONTROLS_HPP_JUNE_25_2026

#include "midi.hpp"
#include "util.hpp"
#include "nexus_adc.hpp"
#include "MspFlash.h"
#ifdef NEXUS_SIM
#include "sim/nexus_sim.hpp"
#endif

////////////////////////////////////////////////////////////////////////////////
// Environment provided by the driver translation unit: the firmware
// sketch on the device, or the host harness off-device. Referenced by
// the controllers below and defined by whoever drives them.
//
//   midi_out:         where MIDI messages are written
//   last_cc_time:     timestamp of the last CC send (gates pitch bend)
//   reset_save_delay: defer the next flash save after a state change
////////////////////////////////////////////////////////////////////////////////
extern cycfi::midi::midi_stream midi_out;
extern uint32_t last_cc_time;
void reset_save_delay();

////////////////////////////////////////////////////////////////////////////////
// Control Mapping:
//
// Main:
//
//    program_change       5-way switch
//    channel_volume       analog
//    pitch_change         analog
//    modulation           analog
//    effect_1             analog
//    effect_2             analog
//    sustain              momentary switch
//
// Aux:
//
//    program_change +5    momentary switch
//    program_change -5    momentary switch
//    program_change +1    momentary switch
//    program_change -1    momentary switch
//    bank_select +1       momentary switch
//    bank_select -1       momentary switch
//
////////////////////////////////////////////////////////////////////////////////

////////////////////////////////////////////////////////////////////////////////
// Constants
////////////////////////////////////////////////////////////////////////////////
int const ch9  = P2_0; //digital
int const ch10 = P1_0; //analog and digital
int const ch11 = P1_3; //analog and digital
int const ch12 = P1_4; //analog and digital
int const ch13 = P1_5; //analog and digital
int const ch14 = P1_6; //analog and digital
int const ch15 = P1_7; //analog and digital

int const aux1 = P2_1; //digital
int const aux2 = P2_2; //digital
int const aux3 = P2_3; //digital
int const aux4 = P2_4; //digital
int const aux5 = P2_5; //digital
int const aux6 = P2_6; //digital


////////////////////////////////////////////////////////////////////////////////
// Flash Utility for persisting MIDI 7 bit data
//
// MSP430 has SEGMENT_B to SEGMENT_D available for applications to use,
// where each segment has 64 bytes. When erased, data in the flash is
// read as 0xff. You can only write once to a data slot, per segment,
// per erase cycle (actually you can write more than once but once a bit
// is reset, you cannot set it with a subsequent write).
//
// MSP430 is spec'd to allow a minimum guaranteed 10,000 erase cycles
// (100,000 erase cycles typical). We store 7-bits data into flash memory
// in a ring buffer fashion to minimize erase cycles and increase the
// possible write cycles. See link below:
//
// http://processors.wiki.ti.com/index.php/Emulating_EEPROM_in_MSP430_Flash)
//
////////////////////////////////////////////////////////////////////////////////
struct flash
{
   typedef unsigned char byte;

   flash(byte* segment_)
      : _segment(segment_)
   {}

   void erase()
   {
      Flash.erase(_segment);
   }

   bool empty() const
   {
      return (*_segment == 0xff);
   }

   byte read() const
   {
      if (empty())
         return 0xff;
      if (byte* p = find_free())
         return *(p - 1);
      return _segment[63];
   }

   void write(byte val)
   {
      byte* p = find_free();
      if (p == 0)
      {
         erase();
         Flash.write(_segment, &val, 1);
      }
      else
      {
         Flash.write(p, &val, 1);
      }
   }

   private:

   byte* find_free() const
   {
      for (int i = 0; i != 64; ++i)
         if (_segment[i] == 0xff)
            return &_segment[i];
      return 0;
   }

   byte* _segment;
};

// Persistent storage for program change / bank select (set by the driver).
extern flash flash_b;
extern flash flash_c;

namespace cycfi
{

////////////////////////////////////////////////////////////////////////////////
// ADC seam. Production reads the background oversampler (nexus_adc.hpp): a
// (10 + os_shift)-bit value per channel, refreshed faster than the loop. A
// NEXUS_SIM build injects synthetic data (shifted up by os_shift so the
// whole pipeline runs at the same bit depth as the device).
////////////////////////////////////////////////////////////////////////////////

// Map a wired analog pin to its ADC10 input channel (A0, A3..A7).
inline uint8_t adc_channel_of(uint16_t pin)
{
   return pin == ch10 ? 0 : pin == ch11 ? 3 : pin == ch12 ? 4
        : pin == ch14 ? 6 : pin == ch15 ? 7 : 5;  // A5 = pitch (ch13)
}

inline uint16_t raw_adc(uint16_t pin)
{
#ifdef NEXUS_SIM
   // 10-bit sim value shifted up to the os_shift bit depth.
   return uint16_t(nexus_sim::sample(pin, millis()) << adc::os_shift);
#else
   return adc::read_os(adc_channel_of(pin));   // blocking oversampled read
#endif
}

// Pots don't travel to the physical ends of their range; clamp to the
// effective 2%-98% travel window and remap to the full 0-1023 range (the CC
// controllers stay 10-bit; the oversampling just cleans the input).
constexpr uint16_t adc_full = 1024 << adc::os_shift;
constexpr uint16_t min_x = uint16_t(adc_full * 0.02);
constexpr uint16_t max_x = uint16_t(adc_full * 0.98);

inline uint16_t analog_read(uint16_t pin)
{
   uint16_t x = raw_adc(pin);
   if (x < min_x)
      x = min_x;
   else if (x > max_x)
      x = max_x;
   return map(x, min_x, max_x, 0, 1023);
}

// iabs / clamp live in util.hpp, shared with the general processor blocks
// (slew_gate, stillness, dc_servo, ...). The pitch-specific blocks are
// defined just above this controller.
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

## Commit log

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2016-12-05 Update license
    [Mother_Board.brd, Mother_Board.sch, Output_Module.brd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]
2016-12-05 update some files
    [IO_Module.brd, IO_Module.sch]
2016-12-07 *Edit Logo *Check BOM *Added 19P Connector Files
    [19P_Connector.brd, 19P_Connector.sch, 2mm_Header_Adaptor.brd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]
2016-12-08 CV Pot and CV Switch drawing pad and dxf files added
    [CV_Pot.DXF, CV_Switch.DXF]
2016-12-09 Added 19 Pin Lemo Elbow Connector PDF and DXF files
    [19P_Connector.DXF, 19P_Connector_2mm_Adaptor.DXF]
2016-12-15 change low pass filter time constant from 256 to 64 change noise gate from 0 to 1
    [nexus_midi.ino]
2016-12-29 Final version 1.0
    [MCU_Module.DXF]
2017-01-04 -add important dimensions
    [CV_Pot.DXF, CV_Switch.DXF]
2017-06-28 * analog_read function to compensate hardware design bug
    [nexus_midi.ino]
2017-07-04 13P Breakout Eagle and BOM Files
    [13P_Connector.brd, 13P_Connector.sch, GK_Roland_Breakout.brd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]
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2017-09-04 Updated BOM
    [19P_Connector.brd, 19P_Connector.sch, 2mm_Header_Adaptor.brd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]
2017-09-05 Removed 13-pin files, moved to "Nu" repository
    [13P_Connector.brd, 13P_Connector.sch, GK_Roland_Breakout.brd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]
2017-09-05 Updated copyright and document number of schematics
    [CV_Pot.sch, CV_Switch.sch, IO_Module.sch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]
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2018-08-14 update main board (version_1.1)
    [Main_Board.brd, Main_Board.sch]
2018-08-14 reupload midi module (version_1.0)
    [MIDI_Module.brd, MIDI_Module.sch]
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2018-08-14 reset devel
    [MCU_Module.DXF, MIDI_Module.brd, MIDI_Module.sch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]
2018-08-17 create version 2.1 and update main and midi modules and delete nexyus cad drawings
    [MCU_Module.DXF, MIDI_Module.brd, MIDI_Module.sch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]
2018-09-02 Update: Main Board MIDI Board MCU Board IO Board
    Delete:
    Mixer Board
    [19P_Connector_2mm_Adaptor.DXF, IO_Module.brd, IO_Module.sch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]
2018-09-18 Slight Changes to MIDI and MCU: - Change BJT Part number on MIDI_Module - Delete Ferrite Bead on MCU_Module
    [MCU_Module.brd, MCU_Module.sch, MIDI_Module.brd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]
2018-10-19 Change 10uF to 1uF in the schematics and BOM file
    [CV_Pot.brd, CV_Pot.sch]
2018-10-23 Thin power traces on main board fixed
    [Main_Board.brd, Main_Board.sch]
2018-10-25 Fixed power traces width
    [Main_Board.brd, Main_Board.sch]
2019-04-01 push dxf files for nexus' front and back panel
    [Nexus_Back_Panel.dxf]
2019-04-16 Pushing CAD drawings for Nexus
    [Nexus.dxf]
2019-11-15 folder renames
    [19p_connector.brd, 19p_connector.dxf, 19p_connector.sch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]
2019-11-15 more folder renames
    [19p_connector.brd, 19p_connector.sch, 2mm_header_adaptor.brd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]
2020-06-03 Update files to version 2.5
    [gk+midi board v2.5.brd, gk+midi board v2.5.sch, io_module.brd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]
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2020-06-03 update schematics
    [gk+midi_module.brd, gk+midi_module.sch, main_board.brd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]
2020-06-03 remove outdated files
    [mcu_module.brd, mcu_module.sch, midi_module.brd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]
2020-06-20 update main board files
    [main_board.brd, main_board.sch]
2020-06-20 update gk+midi files
    [gk+midi_module.brd, gk+midi_module.sch]
2020-06-20 update board
    [gk+midi_module.brd]
2020-06-22 push Nexus peripheral files
    [19p_connector.brd, 19p_connector.sch, 2mm_header_adaptor.brd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]
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2020-06-24 updates for 2 way switch
    [momentary 2 way switch.brd, momentary 2 way switch.sch]
2020-06-29 Fixing Tim Noonan's bug report
    [nexus_midi.ino]
2020-09-21 Update brd and sch file with corrected footprints
    [gk+midi_module.brd, gk+midi_module.sch]
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2021-04-15 updated schematic and bom files for cv pot
    [cv_pot.brd, cv_pot.sch]
2021-04-16 updated schematic, pcb layout and bom file
    [cv_switch.brd, cv_switch.sch]
2021-04-16 add schematic and bom file
    [momentary 2 way switch.brd, momentary 2 way switch.sch]
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2022-01-10 changed some resistors to 0603
    [gk+midi_module.brd, gk+midi_module.sch]
2022-08-29 KiCAD version
    [main_board.kicad_pcb, main_board.kicad_sch]
2022-08-29 Changed transistor to SMD type
    [main_board.kicad_pcb, main_board.kicad_sch]
2022-08-29 Clean update for KiCad
    [main_board.kicad_pcb, main_board.kicad_sch]
2022-08-29 Very clean port to KiCAD
    [main_board.kicad_pcb, main_board.kicad_sch]
2022-09-21 Main board updates
    [main_board.kicad_sch]
2023-02-24 PCB bug fix updates
    [main_board.kicad_pcb]
2023-02-25 renames (don't use special symbols in file names).
    [gk_midi_module.brd, gk_midi_module.sch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]
2023-02-25 make the board perfectly rectangular
    [gk_midi_module.brd]
2023-03-05 Bump version to 2.6
    [main_board.kicad_pcb, main_board.kicad_sch]
2023-03-05 Upgrade to v2.6 - Added short circuit protection - Added soft power switch - Various schematics and PCB layout updates
    [main_board.kicad_pcb, main_board.kicad_sch]
2023-03-06 Migrating I/O board to Kicad and updating to v2.6
    [io_module.brd, io_module.kicad_pcb, io_module.kicad_sch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]
2023-03-06 Added fabrication script
    [io_module.kicad_sch]
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2023-03-06 Change the component to C2977785, plus various PCB refinements
    [main_board.kicad_pcb, main_board.kicad_sch]
2023-04-08 Use AOZ1360AIL load switch
    [main_board.kicad_pcb, main_board.kicad_sch]
2023-04-10 Updates for PCBA and panelization
    [main_board.kicad_pcb, main_board.kicad_sch]
2025-05-08 Production run May 2025
    [main_board.kicad_pcb, main_board.kicad_sch]
2025-05-08 Kicad import from Eagle
    [gk_midi_module.kicad_pcb]
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2026-04-08 Replace two-stage lowpass + gate with dynamic_smoother
    Add integer port of Q DSP dynamic_smoother to util.hpp. State is stored
    in Q8 for sub-integer precision; G0 and Sense are Q8 template parameters
    for base gain and sensitivity. Replace lp1/lp2/gate in controller with a
    single dynamic_smoother<16, 128> instance.
    [nexus_midi.ino]
2026-04-08 Replace two-stage lowpass + gate with dynamic_smoother in pitch_bend_controller
    [nexus_midi.ino]
2026-04-08 Fix Energia compiler: replace non-static member initializers and auto
    [nexus_midi.ino]
2026-04-08 Add dc_block and 14-bit pitch bend with full smoother resolution
    - Add dc_block<Shift> (lowpass-subtraction form, shift instead of divide)
    - Add OutShift template param to dynamic_smoother; pitch_bend_controller
    uses OutShift=4 to preserve Q8 sub-integer bits as 14-bit resolution
    - Replace two-stage lowpass + gate with dynamic_smoother + dc_block in
    pitch_bend_controller; output mapped directly to 14-bit offset binary
    - Update and expand tests: 14-bit smoother convergence/step response,
    dc_block removal, passthrough, and pitch bend centering (17 tests)
    [nexus_midi.ino]
2026-04-08 Increase dc_block TC to ~65s and add init() for instant convergence
    - Add init(s) to dc_block: pre-loads _lp = s << Shift so the filter
    starts converged with no warmup drift at power-on
    - Bump dc_block shift from 13 (~8s) to 16 (~65.5s) for whammy use
    - Call pitch_bend.init(ch13) in setup() to seed DC estimate from the
    sensor's resting position at startup
    - Update tests to use init() instead of long settling loops
    [nexus_midi.ino]
2026-04-08 Increase gate window to 32 and fix init() to use mapped analog_read
    - gate window 16→32 (equivalent to original noise_window=2 at 10-bit scale)
    - init() now uses analog_read() (clamped/mapped) instead of raw analogRead()
    to match the values the main loop feeds the smoother, preventing DC drift
    [nexus_midi.ino]
2026-04-08 Fix pitch_bend_controller startup bugs
    - gate<32,uint16_t>: unsigned underflow (0-32 wraps to 65504) caused
    the gate to pass every sample when val=0; changed to gate<32,int32_t>
    and keep `out` as int32_t through the pipeline.
    - init(): replaced analog_read() (defined in #else !NEXUS_TEST block,
    not visible from setup()) with raw analogRead() which is always
    available; removes the forward-declaration hazard that caused the
    startup -8192 flood.
    [nexus_midi.ino]
2026-04-08 Increase pitch bend gate to 128 to suppress control crosstalk
    ADC ground bounce from other controls was passing through the 32-unit
    gate. 128 units (0.8% of 14-bit range, ~0.2 semitones) filters out
    crosstalk while remaining responsive to intentional pitch bend.
2026-04-08 Replace pitch bend gate with exact-change detection + crosstalk blanking
    Gate was limiting sensitivity; replaced with:
    1. Exact-equality change detection (prev_out): pitch bend sends on any
    14-bit output change, giving maximum resolution with no deadband.
    2. Crosstalk blanking (30 ms): pitch bend output is suppressed for
    30 ms after any other analog control (volume, fx, modulation,
    program change) fires a CC message. This prevents ADC ground-bounce
    from appearing as spurious pitch bend without sacrificing sensitivity
    during normal play.
    [nexus_midi.ino]
2026-04-08 Switch to a DC/Offset servo that tracks offsets only near the deadband window
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2026-04-08 Replace pitch continuity filter with pitch activity filter
    The continuity filter required two gate<16> hits within 4 ms, which was
    too strict for slow/smooth eWhammy motion -- real movement could fail to
    confirm and get dropped.
    The activity filter separates two concerns:
    - gate<2> motion_gt: detects any fine motion to keep a 4 ms activity
    window alive ("is the eWhammy moving?")
    - gate<16> gt: limits MIDI traffic ("is this change worth sending?")
    Isolated crosstalk spikes still fail -- they do not produce the
    sustained fine motion needed to hold the activity window open.
    [nexus_midi.ino]
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2026-04-08 Fix pitch_activity_filter startup false-positive
    last_motion_time=0 caused (now - 0) <= 4 to be true for the first 4 ms
    after boot, arming the filter before any motion was seen. Add an explicit
    `active` flag that starts false and is only set true on the first real
    motion_gt hit.
    [nexus_midi.ino]
2026-04-08 Add pitch bend controller design notes
    Narrative description of signal path, drift compensation, startup
    behaviour, and crosstalk rejection strategy.
2026-04-08 Lower dynamic_smoother base frequency from ~10 Hz to ~2 Hz (G0=2)
    Cytomic's own recommendation is 2 Hz as the base cutoff. G0=16 (~10 Hz)
    was too high, causing the center to drift under idle ADC noise. G0=2
    gives much stronger smoothing at rest while the Sense=128 adaptive term
    still opens the filter fully during active motion (90% in ~12 samples).
    Fixed-gain equivalent at G0=2 takes ~500 samples to reach 90%, making
    the dynamic advantage even more pronounced than before.
    Updated tests to match G0=2 convergence and step-response values.
    [nexus_midi.ino]
2026-04-09 Reset the code pre enhancements.
    [nexus_midi.ino]
2026-04-09 Add moving average pre-filter to pitch bend controller
    Replace lp1 in pitch_bend_controller with an 8-sample moving average
    (moving_average<3>) followed by the original lp1+lp2 cascade. The MA
    provides linear-phase broadband noise reduction (sqrt(8), first null at
    125 Hz) before the leaky integrators finish the smoothing (~21 Hz and
    ~10 Hz). This reduces idle chatter without affecting responsiveness.
    [nexus_midi.ino]
2026-04-09 Add drift compensation to pitch bend controller
    Add offset_servo<13> to pitch_bend_controller to track and remove slow
    Hall effect sensor offset drift (temperature, age). The servo only
    updates within the hardware deadband (±2.5% around center) so sustained
    bends are never absorbed as offset drift. TC ≈ 8 s at 1 kHz.
    Gate moved to 14-bit output space (noise_window*16) to match the
    expanded signal range. Filter chain warmed up in init() with a 200 ms
    ADC sampling loop so loop() starts fully converged.
    [nexus_midi.ino]
2026-04-09 Add CC-blanking crosstalk rejection to pitch bend controller
    ADC ground bounce from CC control movement causes spurious pitch bend
    output. Track the last CC send time in last_cc_time and suppress pitch
    bend output for 80 ms after any CC message. The servo continues to
    update during blanking so drift compensation is unaffected.
    [nexus_midi.ino]
2026-04-09 Increase MA to 16 samples and gate to 48 in pitch bend controller
    Noise floor is ~34 units in 14-bit space. Increased moving_average
    from 8 to 16 samples (4x noise reduction, 8ms latency) and raised the
    gate threshold from 32 to 48 (3 ADC counts) to silence idle chatter
    without affecting real bend sensitivity.
    [nexus_midi.ino]
2026-04-09 Suppress duplicate CC retransmission on crosstalk bounce
    ADC ground bounce from one CC control caused other controllers to
    retransmit their current value. Fix by tracking the last sent 7-bit
    value (prev) and skipping transmission when the value is unchanged.
    [nexus_midi.ino]
2026-04-09 Add 16x oversampling to pitch bend ADC read
    Add analog_read_ex() which averages 16 ADC samples before clipping and
    mapping. Used exclusively for the pitch bend channel (ch13). Improves
    responsiveness near center by smoothing correlated ADC noise before the
    filter chain. Gate remains at 48 (3 ADC counts in 14-bit space).
    [nexus_midi.ino]
2026-04-09 Add hysteresis gate to pitch bend controller
    Replace single gate with a two-threshold hysteresis gate:
    - Idle threshold (40): silences noise floor (~34 units) at rest
    - Active threshold (24): allows smaller movements once a real bend
    is detected, improving responsiveness near center
    - Active state expires after 200 ms of no gate hits, returning to
    idle and re-seeding the idle gate at the current position
    [nexus_midi.ino]
2026-04-09 - Primed the CC controllers - Reverted the oversampling code
    [nexus_midi.ino]
2026-04-09 workaround for MIDI flood at startup
    [nexus_midi.ino]
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2026-04-10 Fix MIDI startup flood, replace CC blanking with dynamic gate, reinstate MA
    - .init3 hook drives P1.2 HIGH as output before global constructors,
    preventing floating pin from generating garbage MIDI bytes at boot
    - Send 0xFF (System Reset) as first byte in setup() to clear receiver
    running status
    - Replace hard CC blanking of pitch bend with dynamic gate: window raises
    to window_high during CC activity (suppresses 1-bit ADC crosstalk),
    reseeds gt.val on transition to prevent zipper effect
    - Reinstate moving_average<3> in pitch bend signal chain to smooth ADC
    noise before servo, eliminating servo hunting / idle oscillation
    - Make gate window runtime-adjustable (remove compile-time te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
    [nexus_midi.ino]
2026-04-10 Replace the old change-tracking gate with a true zero-centered dead-zone gate for pitch bend, while keeping delta-based thresholding only for unipolar CC movement detection.
    [nexus_midi.ino]
2026-04-10 Make startup blanking one-shot and fix near-center pitch bend behavior
    [nexus_midi.ino]
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2026-04-10 Replace IIR s_avg servo seed with fast_update burn-in in init()
    The old approach initialised the servo from a 200-sample IIR mean that
    started at 0, which systematically undershot the sensor's true resting
    value and caused ~50-count startup offset — preventing startup_blank
    from exiting for up to 10 seconds.
    Replace with a 500-sample fast_update loop (TC=64, fast_shift=6).
    Filters are pre-seeded from the first live ADC read so there is no
    filter ramp-up bias. After 500 ms the servo is >99.9% converged to
    whatever value the Hall sensor is at power-on, regardless of thermal
    drift. startup_blank then exits cleanly in ~150 ms as designed.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
    [nexus_midi.ino]
2026-04-10 smooth the jagged staircase due to lower resolution using a leaky integrator
    [nexus_midi.ino]
2026-04-10 Switch MIDI output smoother from lowpass to moving_average
    Replace pb_out_lp (lowpass<8>, TC≈8ms) with pb_out_ma
    (moving_average<2>, N=4, 4ms window) for smoothing the gate
    open/close transitions and interpolating between discrete LP
    limit-cycle steps. The MA gives a cleaner, more uniform
    impulse response that produces visually smooth vibrato curves
    with no staircasing or chatter at the zero crossing.
    [nexus_midi.ino]
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2026-04-13 Stabilize MIDI controller startup and endpoints
    Add raw-domain hysteresis before quantizing analog CC inputs to 7-bit MIDI values, so endpoint noise does not chatter between adjacent CC values. Snap and hold the 0/127 endpoints with a release band to preserve full-range output.
    Keep pitch bend muted during startup until the centered signal has remained stable for two seconds, preventing noisy boards from arming a small bend while the Hall/reference path settles. Raise the post-filter cutoff to make whammy tracking more responsive.
    [nexus_midi.ino]
2026-04-13 Refine pitch bend startup guard
    Remove the timed startup blanking that could leave the whammy feeling unresponsive after boot.
    Replace it with a one-shot center guard that mutes only near-center startup drift until the first real whammy movement, then falls back to the normal narrow center window so vibrato crossings are not flattened.
    [nexus_midi.ino]
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2026-04-16 io_module fab updates; update to latest kicad
    [io_module.kicad_pcb, io_module.kicad_sch]
2026-04-24 Re-added BOM
    [bom.xls]
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2026-06-27 nexus_midi: pitch-bend center-stability (feed-forward predictor)
    Clean-room digital port of the eWhammy analog center-stability, then evolved past it: the spring-return hysteresis is COMPUTED from the deflection (feed-forward predictor off a fixed seed) rather than chased reactively, so the off-center latch is structurally impossible -- no watchdog. A decoupled slow Pre-DC servo clipped to the max physical wander, a relaxing post-corrector, a velocity/dwell center detent, an input slew gate (rejects programmer-glitch reference shifts), and a startup validity gate. Validated by replaying real hardware captures and on the bench.
    Granular dev history (reactive servo, k-learning experiment, etc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
    [host_sim.cpp, nexus_controls.hpp, nexus_midi.ino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]
2026-06-27 nexus_midi: decompose pitch_bend_controller into unit-tested blocks
    Eight processor blocks, each unit-tested: the general ones (slew_gate, stillness, dc_servo, dynamic_smoother, moving_average_n) to util.hpp as templates; the pitch-specific ones (hysteresis_predictor, post_corrector, center_detent, output_stage, settle_gate) as non-template classes beside the controller. Behavior-preserving (host suite + capture replay unchanged). Deleted the unused offset_servo.
    Per-block granular history on the center-stability-refactor branch.
    [host_sim.cpp, nexus_controls.hpp, unit_blocks.cpp]
2026-06-27 nexus_midi: 12-bit ADC oversampling for all controllers + faster CC response
    All 6 analog channels are oversampled 16x and decimated to 12 bits (+2
    real bits; the Hall/pot noise is the dither). adc::read_os() is a BLOCKING
    burst of the stock one-shot ADC10 conversion (the analogRead path), looped
    16x with a leading S&H-settle throwaway -- no ISR, no .bss, deterministic,
    works standalone on this 512-byte part. Background DTC/ISR designs were
    tried first and both failed (the DTC overran the stack into the WDT globals
    -> reboot loop; a free-run ISR read 0 standalone). The time-based control
    loop absorbs the ~0.1 ms/channel.
    Input-domain pitch constants (scale, nominal, sm_sense, slew, band_thr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
    [nexus_controls.hpp, nexus_midi.ino, unit_blocks.cpp]
2026-06-27 nexus_midi: correct note 1 -- the removed k-learner sampled the output
    It read corrected (post-servo, post-prediction), which the servo had already nulled, so it never saw the error -- not 'a wash' for no reason. Learning belongs in the input domain (dev_m); see KB k_learning.md. Comment-only.
    [nexus_controls.hpp]
2026-06-28 nexus_midi: inertial_corrector center-stability (slope hang-land + 10 s watchdog)
    Squash of the center-stability branch (10 commits). Replaces the feed-forward
    predictor / k_learner / post_corrector / center_detent with a single
    inertial_corrector: a noise-gated hang-lander that nulls a stalled release to
    center via low-passed slope detection (snappy ~150 ms snap), plus a
    freeze_watchdog that flushes an output stuck off-center for 10 s (the
    programmer-disconnect reference-shift backstop). Dead code removed; the
    pitch-bend controller refactored into unit-tested blocks.
    A displacement-stall variant (tracks slow manual descents, ~500 ms land) was
    trialed and reverted in favor of the snappy slo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
    [host_sim.cpp, nexus_controls.hpp, nexus_sim.hpp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]
2026-06-29 nexus_midi: merge center-stability landing refinements (squash) + refresh image
    Squash of the center-stability landing work onto master: the vigor-adaptive
    exponential hang-land (peak-slope sized, slope/tau clamped, never-cross-center
    clamp) and the 1 ST -> 4 ST audibility-aligned arm threshold. Refreshes the
    prebuilt no-diag production image nexus_midi.hex (.text 9520, diag OFF).
    [nexus_controls.hpp]
2026-06-29 nexus_midi: format all source to the 77-column convention
    Comments / formatting only -- binary unchanged (.text 9520, host_sim 11/11).
    Wraps every source file to <= 77 cols (prose, function comments, and trailing
    comments alike; long member types aliased via typedef for the device GCC 4.6).
    Fixes the stale +/-1 ST arm references to +/-4 ST. Normalizes the decorative
    full-width dividers to 80 cols. Adds the blank-line spacing (one empty line
    after a paragraph, and between multi-line list items). Files: nexus_controls,
    nexus_adc, util, midi, the .ino, sim/nexus_sim, and the test harness.
    [host_sim.cpp, nexus_controls.hpp, nexus_midi.ino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]
2026-06-29 nexus_midi: host_sim regression for the eWhammy-not-connected case
    Adds a no-input scenario to the default host_sim suite: pins the pitch ADC
    at 0 (the R27 pulldown with nothing plugged in) for 12 s through the real
    setup()/loop(), and asserts the firmware stays MUTED at center -- never goes
    live, emits only the boot-center message, never lands off-center, ends
    centered. Runs after the gesture suite (skipped under --feed, which drives
    its own input). host_sim 15/15, unit_blocks green; host-only, device image
    unchanged.
    [host_sim.cpp]

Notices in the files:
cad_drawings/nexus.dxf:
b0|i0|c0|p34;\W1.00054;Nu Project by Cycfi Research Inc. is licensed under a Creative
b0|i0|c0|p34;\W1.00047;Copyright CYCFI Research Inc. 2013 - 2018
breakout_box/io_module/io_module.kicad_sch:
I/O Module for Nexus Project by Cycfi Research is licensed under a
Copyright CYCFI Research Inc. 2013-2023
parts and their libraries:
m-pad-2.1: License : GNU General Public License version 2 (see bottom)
